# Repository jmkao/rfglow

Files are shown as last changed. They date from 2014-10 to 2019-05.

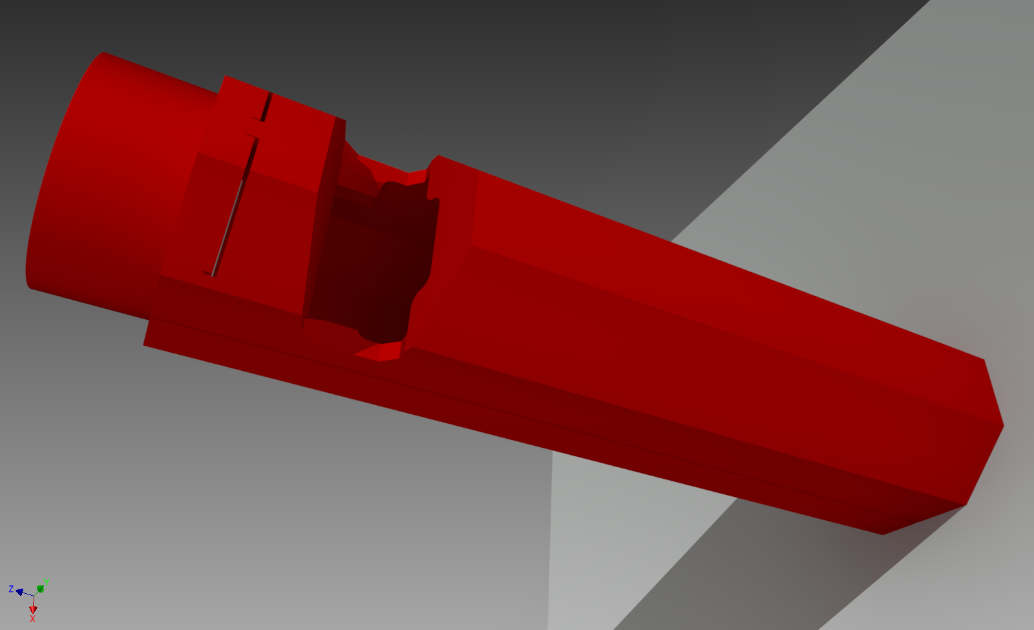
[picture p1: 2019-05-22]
inventor/KBHandle/KBHandle-Assembly.png

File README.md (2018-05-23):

rfglow
======

All the parts for an RF controlled RGB glow stick, in the style of a Ruifan KING BLADE (キングブレード http://ruifan.co.jp/pro_kb_x.html). In fact, making this work requires a diffuser from a KB since the diffuser itself cannot be 3D printed.

There are 3 basic component areas:
 * Electronics (Eagle files and BOM)
 * Microcontroller code (Arduino code)
 * Plastic handle (Inventor IPT files and STL files for 3D printing)

## Project Chat



## Status
This project is fairly usable, although could use some additional polish. All of the areas are sufficiently functional to demonstrate a proof of concept, but requires more testing before a device could actually be used in a physically demanding environment.

The primary items that need work are:
 * App for the BLE master
 * Handle design - Refactor to be more compact and with more practical design, especially for the coupler and attachemnt of the two halves
 * RF Master - Integrate a 0.96" color OLED screen, then design a PCB for it
 * RF Slave - Code something for the button to do

Then there are other interesting things that one could do with a microcontroller:
 * Fade commands
 * Color cycling commands
 * Slaves also act as command repeaters

Contributions welcome in all areas.

# Electronics
The PCB design is in the eagle folder and contains the schematic, PCB layout, and a set of gerber files (zipped together) for sending to a PCB fabrication service like Osh Park or Seeedstudio. (I had my first set made at Osh Park.)

The PCB is really a kind of motherboard for a variety of sub-assemblies (other boards sold as modules), principally:
 * RFBee from Seeedstudio
  * A Panstamp from panstamp.com can also be used as it has the same hardware (and is more compact, even). However, I don't have  board design to accomodate one (yet!)
 * Pololu S7V8A Adjustable Regulator (http://www.pololu.com/product/2118)
  * The potentiometer on this should be adjusted to output 3.7V before putting in place on the board
 * STP04CM05 LED Driver
  * The one I used for this design is a 14-DIP package not officially mentioned on the datasheet. I got mine from Digi-key (http://www.digikey.com/product-detail/en/STP04CM05B1R/497-6940-5-ND/1852497).
 * Vollong 3W RGB High Power Led and a matching lens
  * I got mine from http://www.superbrightleds.com/moreinfo/component-leds/vollong-3w-rgb-high-power-led/899/2214/
  * You'll need to bridge together the - leads into a common cathode configuration (the STP04CM05 is a sink driver)
 * Grove connectors from Seeedstudio cut up
  * I'm sure there's some spec for these, but I had a bunch of these lying around and used them for this purpose. Since you'll have to order an RFBee from them, you might as well get a bunch of cables from them (male on both sides so each cable can make two connectors) and PCB receptacles.
  * The color convention I'm using is:
    * Cable Red --> LED Red
    * Cable White --> LED Green
    * Cable Yellow --> LED Blue
    * Cable Black --> LED Common Ground
 * Adafruit nRF8001 (https://www.adafruit.com/products/1697)
  * Used for the rfglow_ble code which will relay commands from the nRF8001's BLE interface to the glow sticks.
  * Would allow a mobile app (e.g. iOS, Android) on a BLE capable device to control the glow sticks with a more advanced interface
  * A panstamp must be used as the microcontroller to build this device because the nRF8001 must be wired to the hardware SPI interface, and the RFBee does not expose the pins necessary to do this.

The version of the BLE master in this repository is for an unamplified version that uses a Panstamp. There is also an amplified designed that uses a CC1101+CC1190 evaluation module. The schematics and board layout for that were done in Upverter and are available at https://upverter.com/jkao/e86d81299623de9d/RFGlow-BLE-CC1109-Relay/

# Microcontroller Code

Arudino Code for 1.0.x.

 * rfglow_slave
  * Code for the glow sticks themselves
 * rfglow_master
  * Code for a potential master
  * Currently supported gestures:
   * Color change - short press on left and right
   * LED on/off - long press on the center to toggle
   * Auto color cycling mode - short press on center to toggle
   * Brightness change - long press on left or right
 * rfglow_ble
  * BLE based master that will relay color change commands over BLE to the RF glow sticks
  * Usable today for simple color changes with the iOS nRF UART or LightBlue apps
   * For nRF UART, send ASCII of 3 numbers separated by spaces, like "270 255 32\n". This is an HSV value, with the first digit as hue (0-359), second digit as saturation (0-255), and third digit as brightness (0-255)
   * For LightBlue (and really for any app you design yourself), send 4 bytes to the write characteristic of the service. The first 2 bytes are a 16-bit unsigned int for hue (only valid from 0-355), the 3rd byte is the unsigned 8-bit int for saturation, the 4th byte is the unsigned 8-bit int for brightness.
 * rfglow_serial
  * Code for when the master is connected to a computer, in which case you can enter the hue, saturation, and brightness as tuples over the serial line to send the command.
  * This code hasn't been touched in a while, and needs to have the radio settings from rfglow_master copied into it for it to actually work with the current version of rfglow_slave

The Arduino code depends on the following libraries:
 * ShiftPWM from https://github.com/elcojacobs/ShiftPWM
 * Panstamp for Arudino 1.0.x, currently panstamp_library.zip from http://www.panstamp.com/downloads
  * Uses only the CC1101 libraries and not the SWAP stack
 * ClickButton from https://code.google.com/p/clickbutton/downloads/list
  * Only needed by rfglow_master currently for the button behavior

# Plastic Handle

Autodesk Inventor parts and assembly with the current design, to be FFF 3D printed (e.g. <45 degree overhangs, etc...).

This design is quite messy becuase my CAD skills are weak, and the parameters are difficult to adjust. However, it is functional with the following features:
* Lip-and-groove attachment between top and bottom halves to facilitate alignment
 * There is some clearance, so the groove is deeper than the lip sticks out
* Coupler to screw on a king blade diffuser on one end, then attach to the handle
* Cups for magnets to help hold the top and bottom together (0.25" X 0.125" X 0.0625" rare earth)

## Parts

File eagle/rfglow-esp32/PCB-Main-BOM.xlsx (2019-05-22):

Qty | Designator | MPN | Link
2 | R4, R13 | 301010456
1 | R11 | 301010028
1 | C9 | 302010024
1 | USB1 | 320010003
2 | R5, R12 | 301010047
8 | C1, C4, C5, C6, C7, C8, C10, C11 | 302010053
3 | R3, R8, R9 | 301010043
2 | C2, C3 | 302010040
1 | R2 | 301012017
1 | D1 | 304020032
1 | J2 | 320110026
2 | R6, R7 | 301010010
1 | R1 | 301010069
1 | J1 | 320110032
1 | R10 | RC0402JR-0756RL
1 | IC3 | AP2112K-3.3TRG1
1 | U1 | CH340C | https://lcsc.com/product-detail/USB_CH340C_C84681.html
1 | SW1 | 311030001
1 | SW2 | 311020518
1 | Q2 | 305030075
1 | L1 | 303010527
1 | IC1 | TLC59116IPWR | https://lcsc.com/product-detail/LED-Drivers_TI_TLC59116IPWR_TLC59116IPWR_C131194.html
1 | IC2 | TPS63020DSJR | https://lcsc.com/product-detail/DC-DC-Converters_TI_TPS63020DSJR_TPS63020DSJR_C15483.html
1 | Q1 | UMH3NTN | https://lcsc.com/product-detail/Digital-Transistors_ROHM_UMH3NTN_UMH3NTN_C123008.html

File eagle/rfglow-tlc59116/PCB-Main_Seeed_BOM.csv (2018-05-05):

Designator | Manufacturer Part Number | Quantity
C1 | 302010024 | 1
R5 | 301010047 | 1
R8, R9 | 301010509 | 2
C2, C3 | 302010040 | 2
R1, R2, R3, R4 | 301010138 | 4
R6, R7 | 301010010 | 2
J1 | 320110032 | 1
J2 | 320110026 | 1
X1 | 874380643 | 1
SW2 | 311020045 | 1
SW1 | 311030001 | 1
IC1 | TLC59116IPWR | 1
ANT1 | 320110048 | 1
U1 | 310030099 | 1

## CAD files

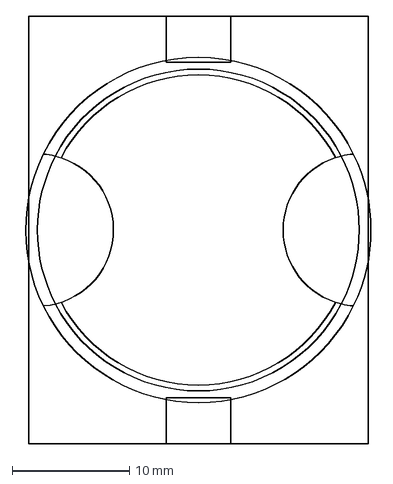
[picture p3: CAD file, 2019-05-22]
inventor/KBHandle/LED Tab Profile.dxf
30.8 x 36.5 mm

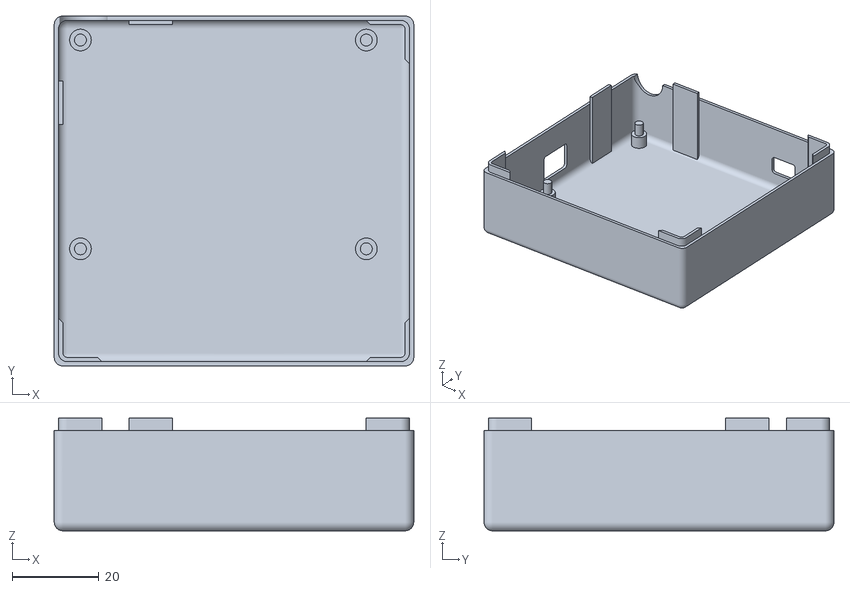
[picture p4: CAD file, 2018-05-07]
models/Box - Part 1.stl
83.0 x 80.8 x 26.0

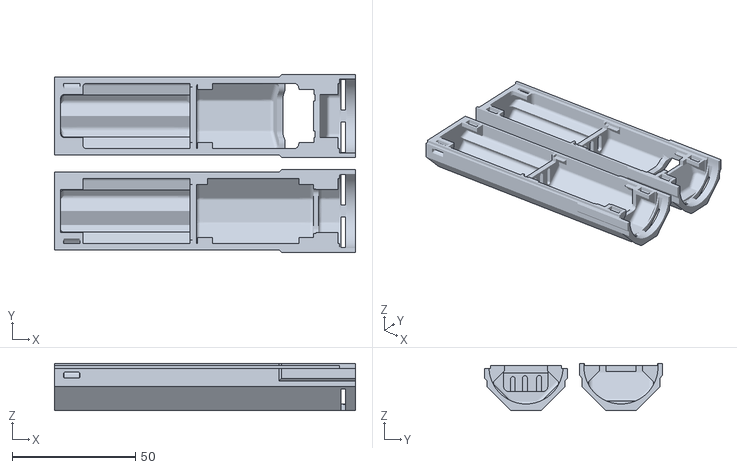
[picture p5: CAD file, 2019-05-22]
inventor/KBHandle/Handle-Set.stl
122.0 x 72.0 x 19.2

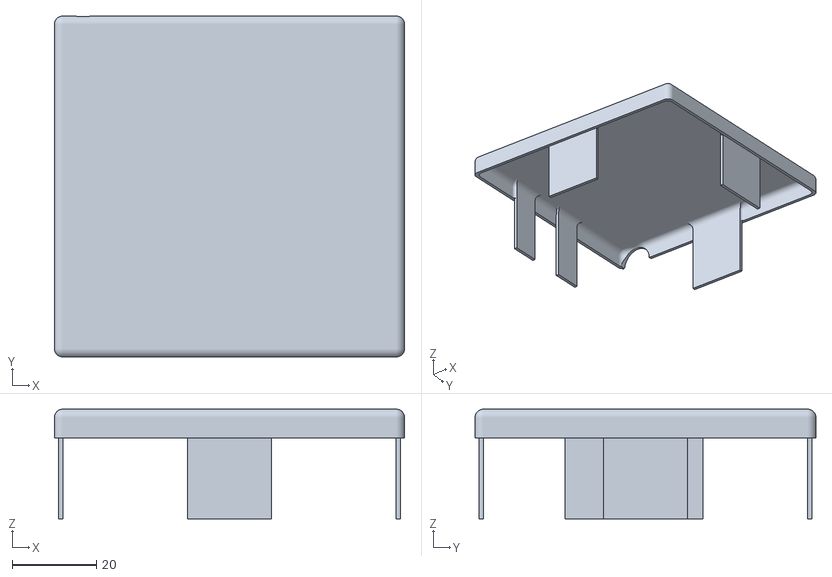
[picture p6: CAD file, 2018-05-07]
models/Box - Part 2.stl
83.0 x 80.8 x 26.0

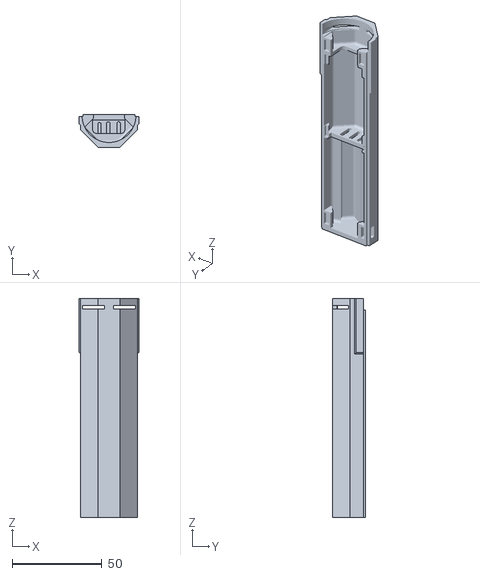
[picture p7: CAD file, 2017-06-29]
inventor/KBHandle/Handle-Bottom.stl
33.5 x 18.2 x 122.0

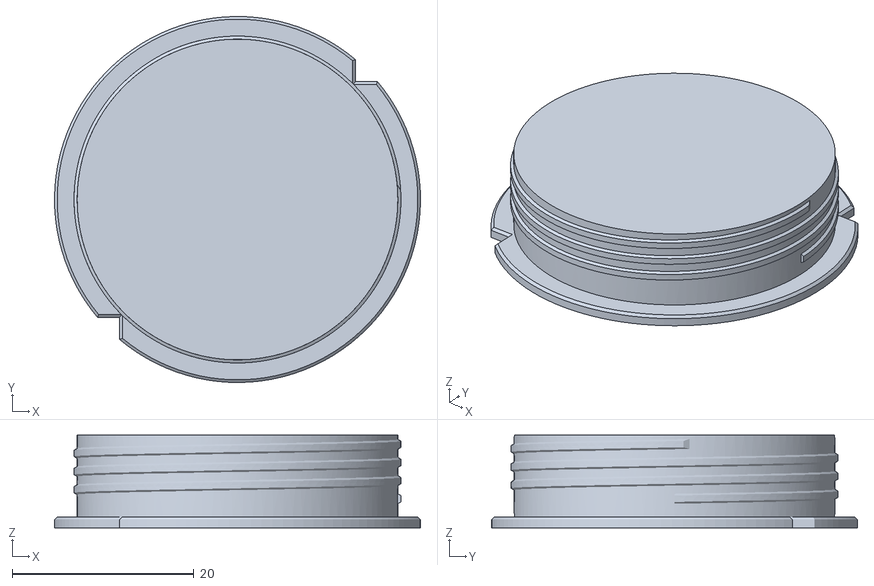
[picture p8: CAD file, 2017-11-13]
models/Cap-Solid.stl
40.3 x 40.3 x 10.2

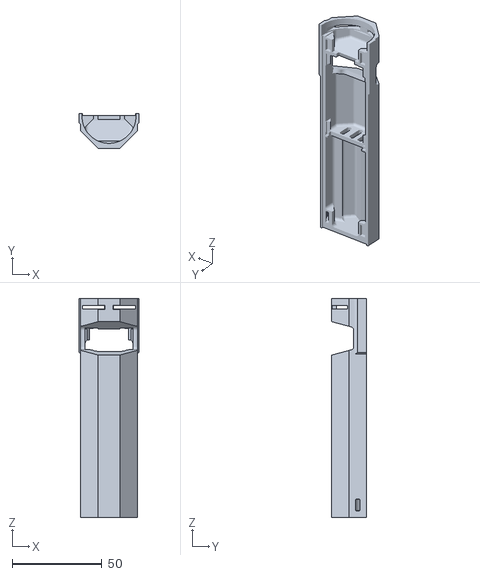
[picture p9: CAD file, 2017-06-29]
inventor/KBHandle/Handle-Top.stl
33.5 x 19.2 x 122.0

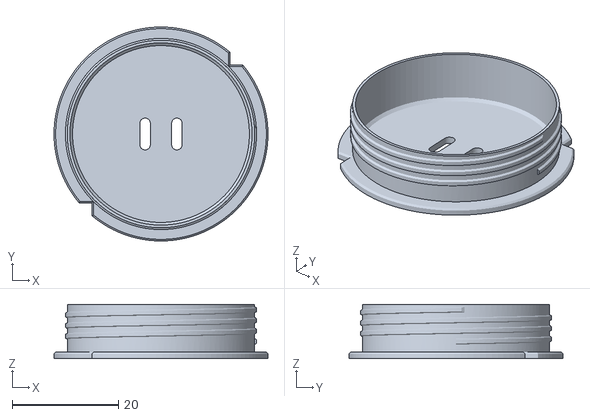
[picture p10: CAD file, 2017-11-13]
models/Cap.stl
40.3 x 40.3 x 10.2

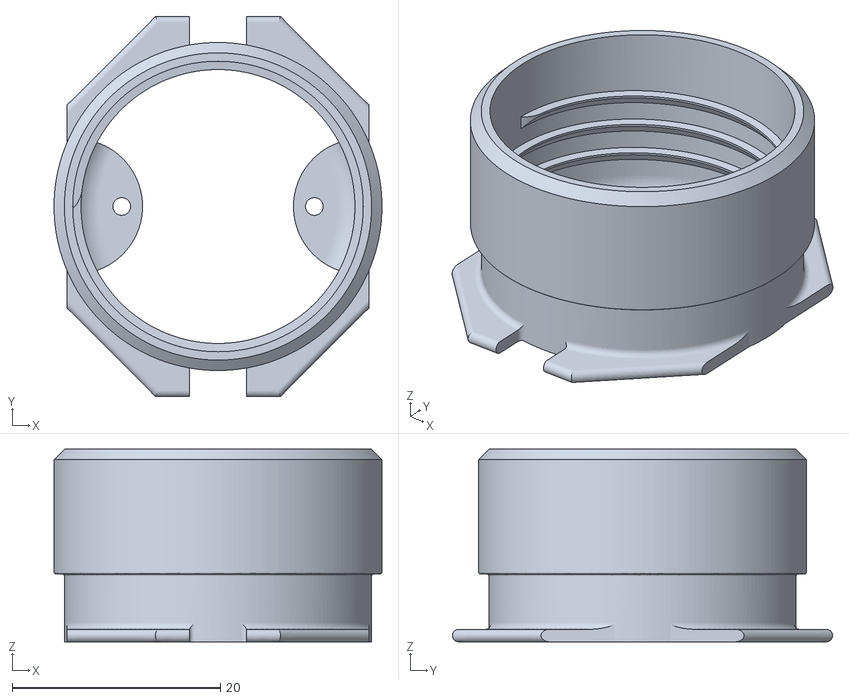
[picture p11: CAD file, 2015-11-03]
inventor/KBHandle/DiffuserCoupler.stl
31.5 x 36.5 x 18.5

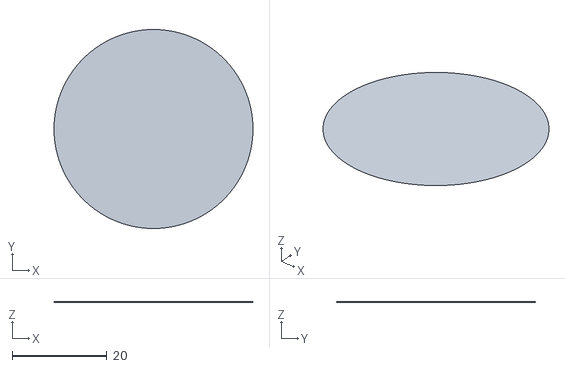
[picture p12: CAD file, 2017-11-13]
models/Cylinder.stl
42.0 x 42.0 x 0.02

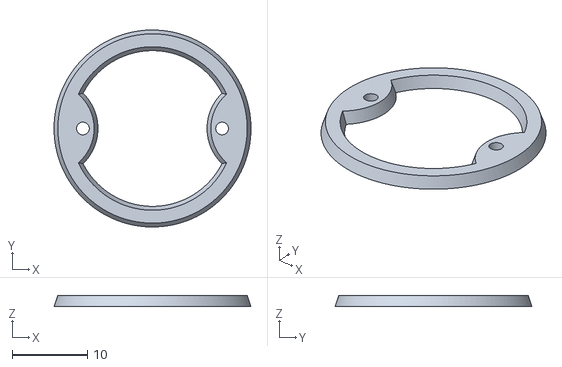
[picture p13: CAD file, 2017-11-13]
models/Coupler.stl
26.2 x 26.2 x 1.50

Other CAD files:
inventor/KBHandle/DiffuserCoupler.ipt
inventor/KBHandle/Handle-Bottom.ipt
inventor/KBHandle/Handle-Top-Battery.ipt
inventor/KBHandle/Handle-Top-Main.ipt
inventor/KBHandle/Handle-Top.ipt
inventor/KBHandle/KBHandle.iam

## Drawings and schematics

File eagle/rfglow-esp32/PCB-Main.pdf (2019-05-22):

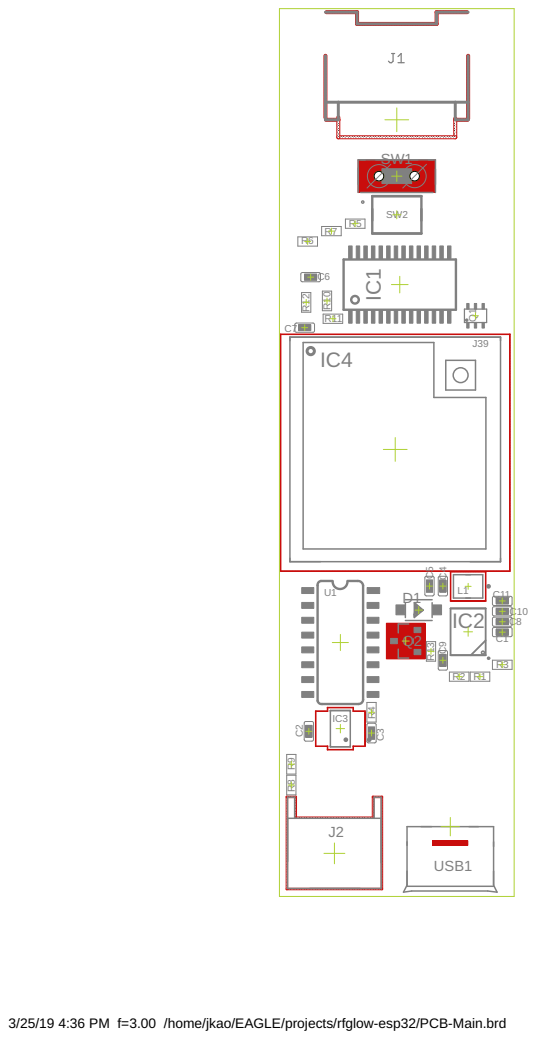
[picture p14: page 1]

R5
R7
R6

3/25/19 4:36 PM f=3.00 /home/jkao/EAGLE/projects/rfglow-esp32/PCB-Main.brd

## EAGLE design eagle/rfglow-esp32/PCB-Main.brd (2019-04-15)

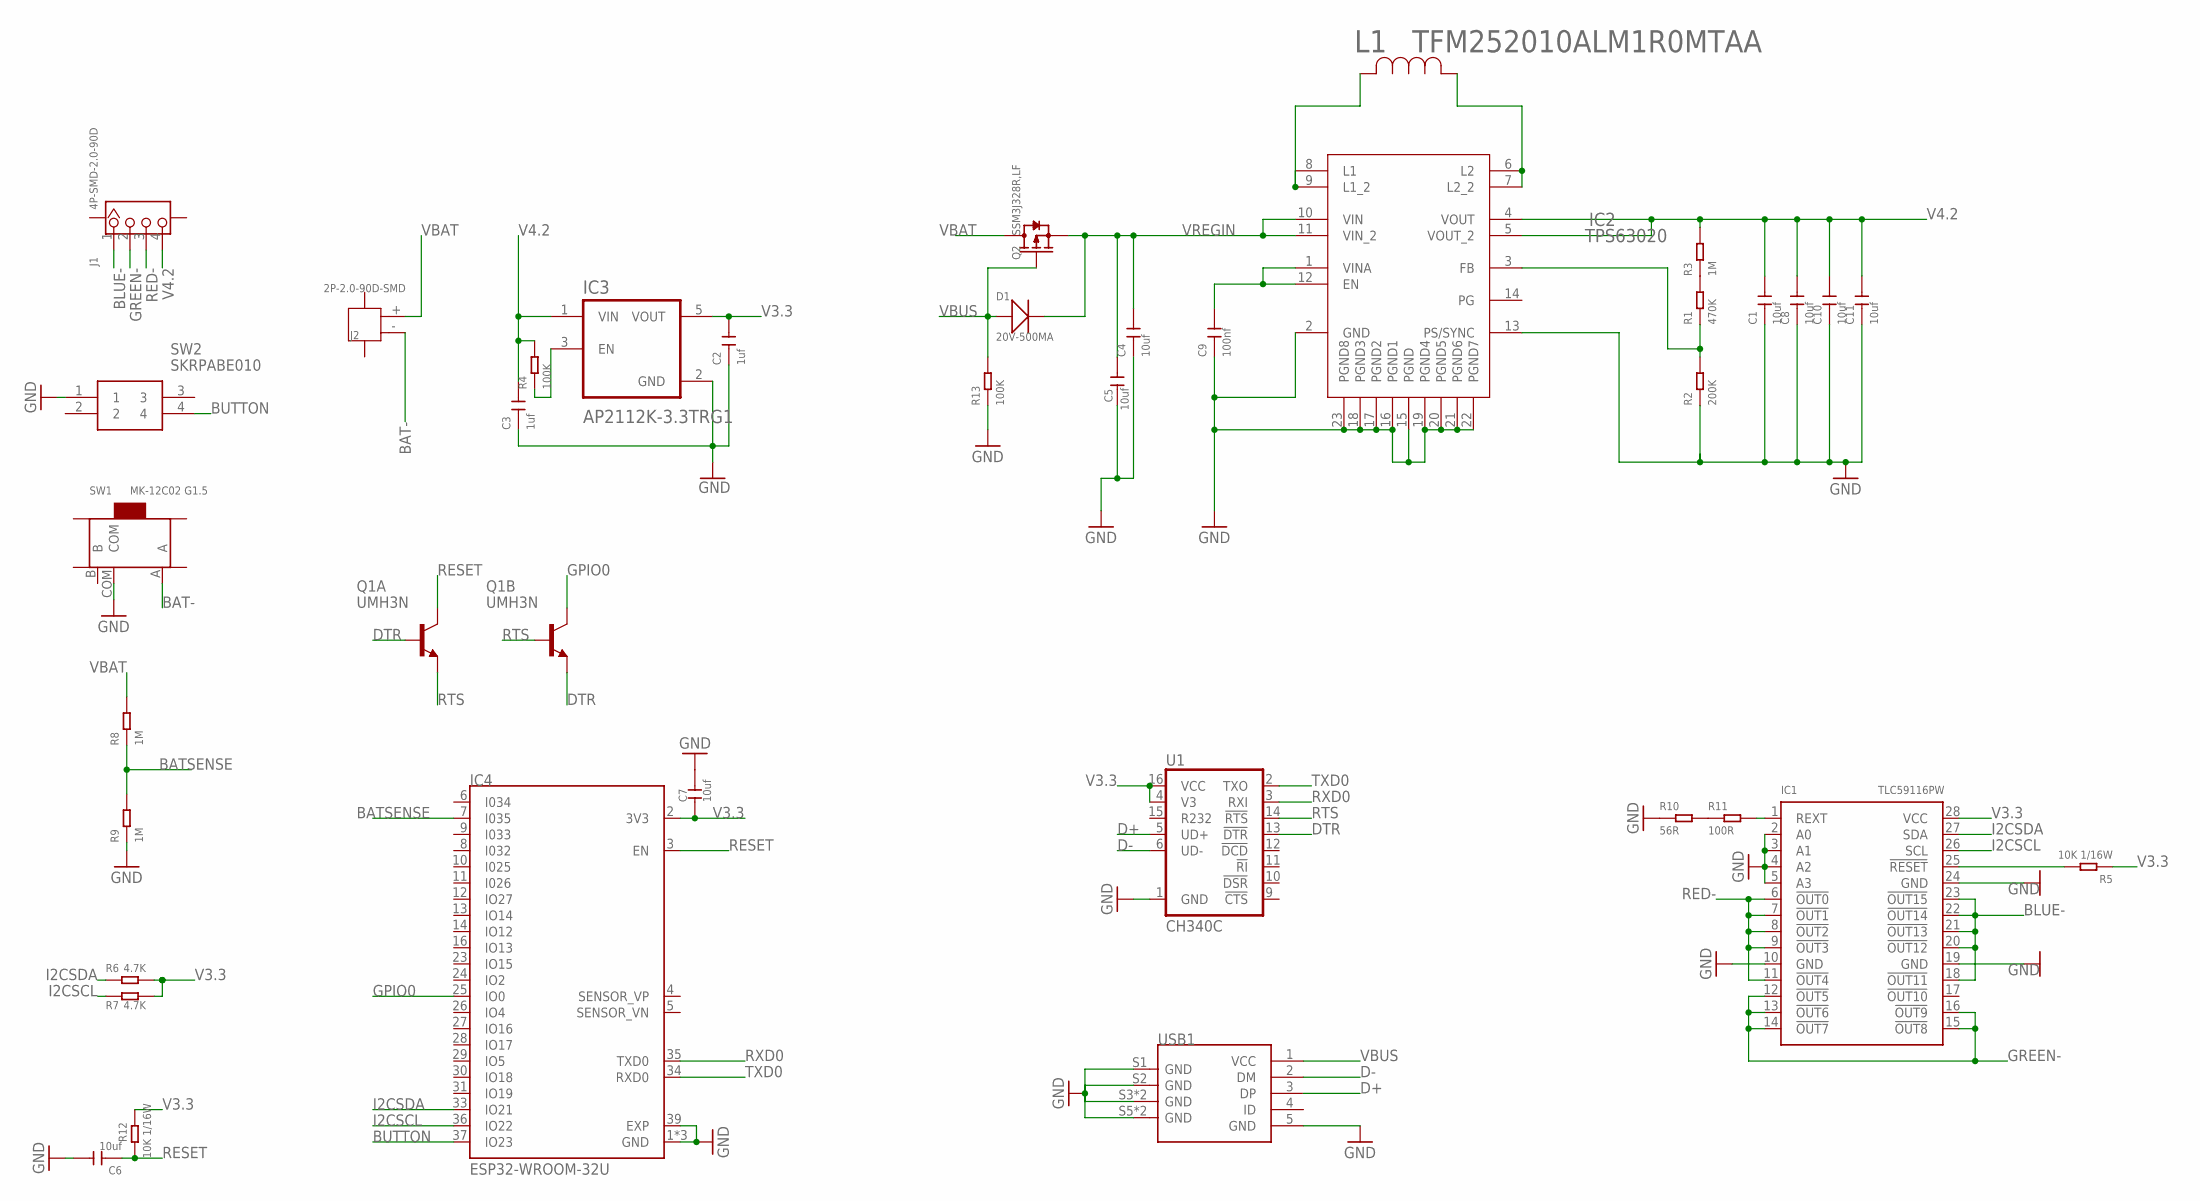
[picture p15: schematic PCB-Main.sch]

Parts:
C1, C4, C5, C6, C7, C8, C10, C11: 10uf; C0402
C2, C3: 1uf; C0402
C9: 100nf; C0402
D1: 20V-500MA; SOD-123
IC1: TLC59116PW; PW_R-PDSO-G28
IC2: TPS63020; QFN14-3X4MM
IC3: AP2112K-3.3TRG1; SOT95P285X140-5N
IC4: ESP32-WROOM-32U; XCVR_ESP32-WROOM-32U
J1: 4P-SMD-2.0-90D; HW4-SMD-2.0-90D
J2: 2P-2.0-90D-SMD; HW2-SMD-2.0-90D
L1: TFM252010ALM1R0MTAA; IND_1008
Q1: UMH3N; UMT6
Q2: SSM3J328R,LF; SOT-23
R1: 470K; R0402
R2: 200K; R0402
R3, R8, R9: 1M; R0402
R4, R13: 100K; R0402
R5, R12: 10K 1/16W; R0402
R6, R7: 4.7K; R0402
R10: 56R; R0402
R11: 100R; R0402
SW1: MK-12C02 G1.5; SW7-SMD-L6.7X2.7X3.2MM
SW2: SKRPABE010; SMT(4.2X3.2)
U1: CH340C; SO016
USB1: 10118193-0001LF; MICRO-USB5+6P-SMD-0.65-B

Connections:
BAT-: J2.- (2), SW1.A
BATSENSE: IC4.7 (I035), R8.1, R9.2
BLUE-: IC1.18 (!OUT11), IC1.20 (!OUT12), IC1.21 (!OUT13), IC1.22 (!OUT14), IC1.23 (!OUT15), J1.1
BUTTON: IC4.37 (IO23), SW2.4
D+: U1.5 (UD+), USB1.3 (DP)
D-: U1.6 (UD-), USB1.2 (DM)
DTR: Q1.2 (B), Q1.4 (E), U1.13 (!DTR)
GND: C1.1, C2.1, C3.1, C4.1, C5.1, C6.2, C7.2, C8.1, C9.1, C10.1, C11.1, IC1.2 (A0), IC1.3 (A1), IC1.4 (A2), IC1.5 (A3), IC1.10 (GND), IC1.19 (GND), IC1.24 (GND), IC2.2 (GND), IC2.13 (PS/SYNC), IC2.15 (PGND), IC2.16 (PGND1), IC2.17 (PGND2), IC2.18 (PGND3), IC2.19 (PGND4), IC2.20 (PGND5), IC2.21 (PGND6), IC2.22 (PGND7), IC2.23 (PGND8), IC3.2 (GND), IC4.1 (GND), IC4.15 (GND), IC4.38 (GND), IC4.39 (EXP), R2.1, R9.1, R10.1, R13.1, SW1.COM, SW2.1, U1.1 (GND), USB1.5 (GND), USB1.S1 (GND), USB1.S2 (GND), USB1.S3 (GND), USB1.S4 (GND), USB1.S5 (GND), USB1.S6 (GND)
GPIO0: IC4.25 (IO0), Q1.3 (C)
GREEN-: IC1.12 (!OUT5), IC1.13 (!OUT6), IC1.14 (!OUT7), IC1.15 (!OUT8), IC1.16 (!OUT9), J1.2
I2CSCL: IC1.26 (SCL), IC4.36 (IO22), R7.1
I2CSDA: IC1.27 (SDA), IC4.33 (IO21), R6.1
unnamed: C9.2, IC2.1 (VINA), IC2.12 (EN)
unnamed: IC1.1 (REXT), R11.2
unnamed: R1.2, R3.1
unnamed: IC3.3 (EN), R4.1
unnamed: R10.2, R11.1
unnamed: IC2.8 (L1), IC2.9 (L1_2), L1.2
unnamed: IC1.25 (!RESET), R5.2
unnamed: IC2.6 (L2), IC2.7 (L2_2), L1.1
unnamed: IC2.3 (FB), R1.1, R2.2
RED-: IC1.6 (!OUT0), IC1.7 (!OUT1), IC1.8 (!OUT2), IC1.9 (!OUT3), IC1.11 (!OUT4), J1.3
RESET: C6.1, IC4.3 (EN), Q1.6 (C), R12.1
RTS: Q1.1 (E), Q1.5 (B), U1.14 (!RTS)
RXD0: IC4.35 (TXD0), U1.3 (RXI)
TXD0: IC4.34 (RXD0), U1.2 (TXO)
V3.3: C2.2, C7.1, IC1.28 (VCC), IC3.5 (VOUT), IC4.2 (3V3), R5.1, R6.2, R7.2, R12.2, U1.4 (V3), U1.16 (VCC)
V4.2: C1.2, C3.2, C8.2, C10.2, C11.2, IC2.4 (VOUT), IC2.5 (VOUT_2), IC3.1 (VIN), J1.4, R3.2, R4.2
VBAT: J2.+ (1), Q2.3 (D), R8.2
VBUS: D1.+, Q2.1 (G), R13.2, USB1.1 (VCC)
VREGIN: C4.2, C5.2, D1.-, IC2.10 (VIN), IC2.11 (VIN_2), Q2.2 (S)

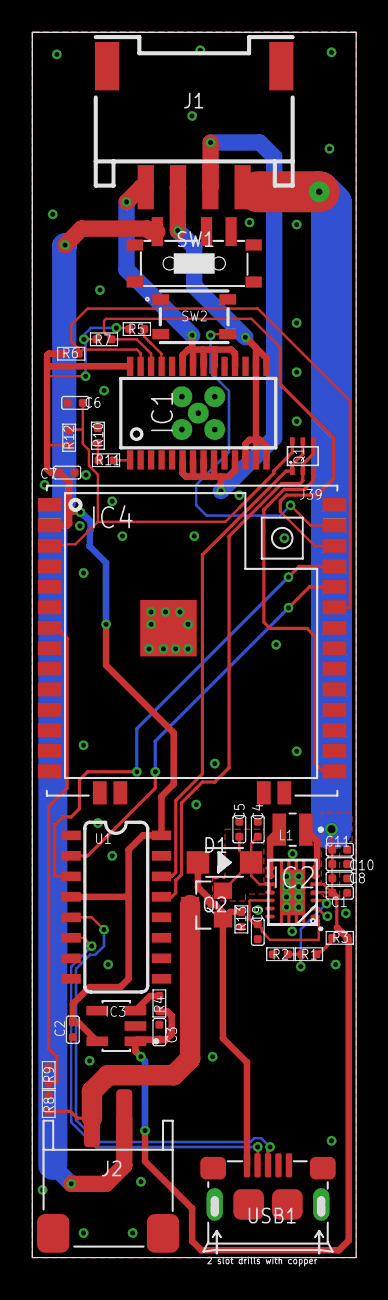
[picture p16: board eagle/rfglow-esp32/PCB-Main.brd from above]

Board: 2 copper layers, 20.1 x 75.9 mm, 38 parts (0 on the bottom side), 31 nets.

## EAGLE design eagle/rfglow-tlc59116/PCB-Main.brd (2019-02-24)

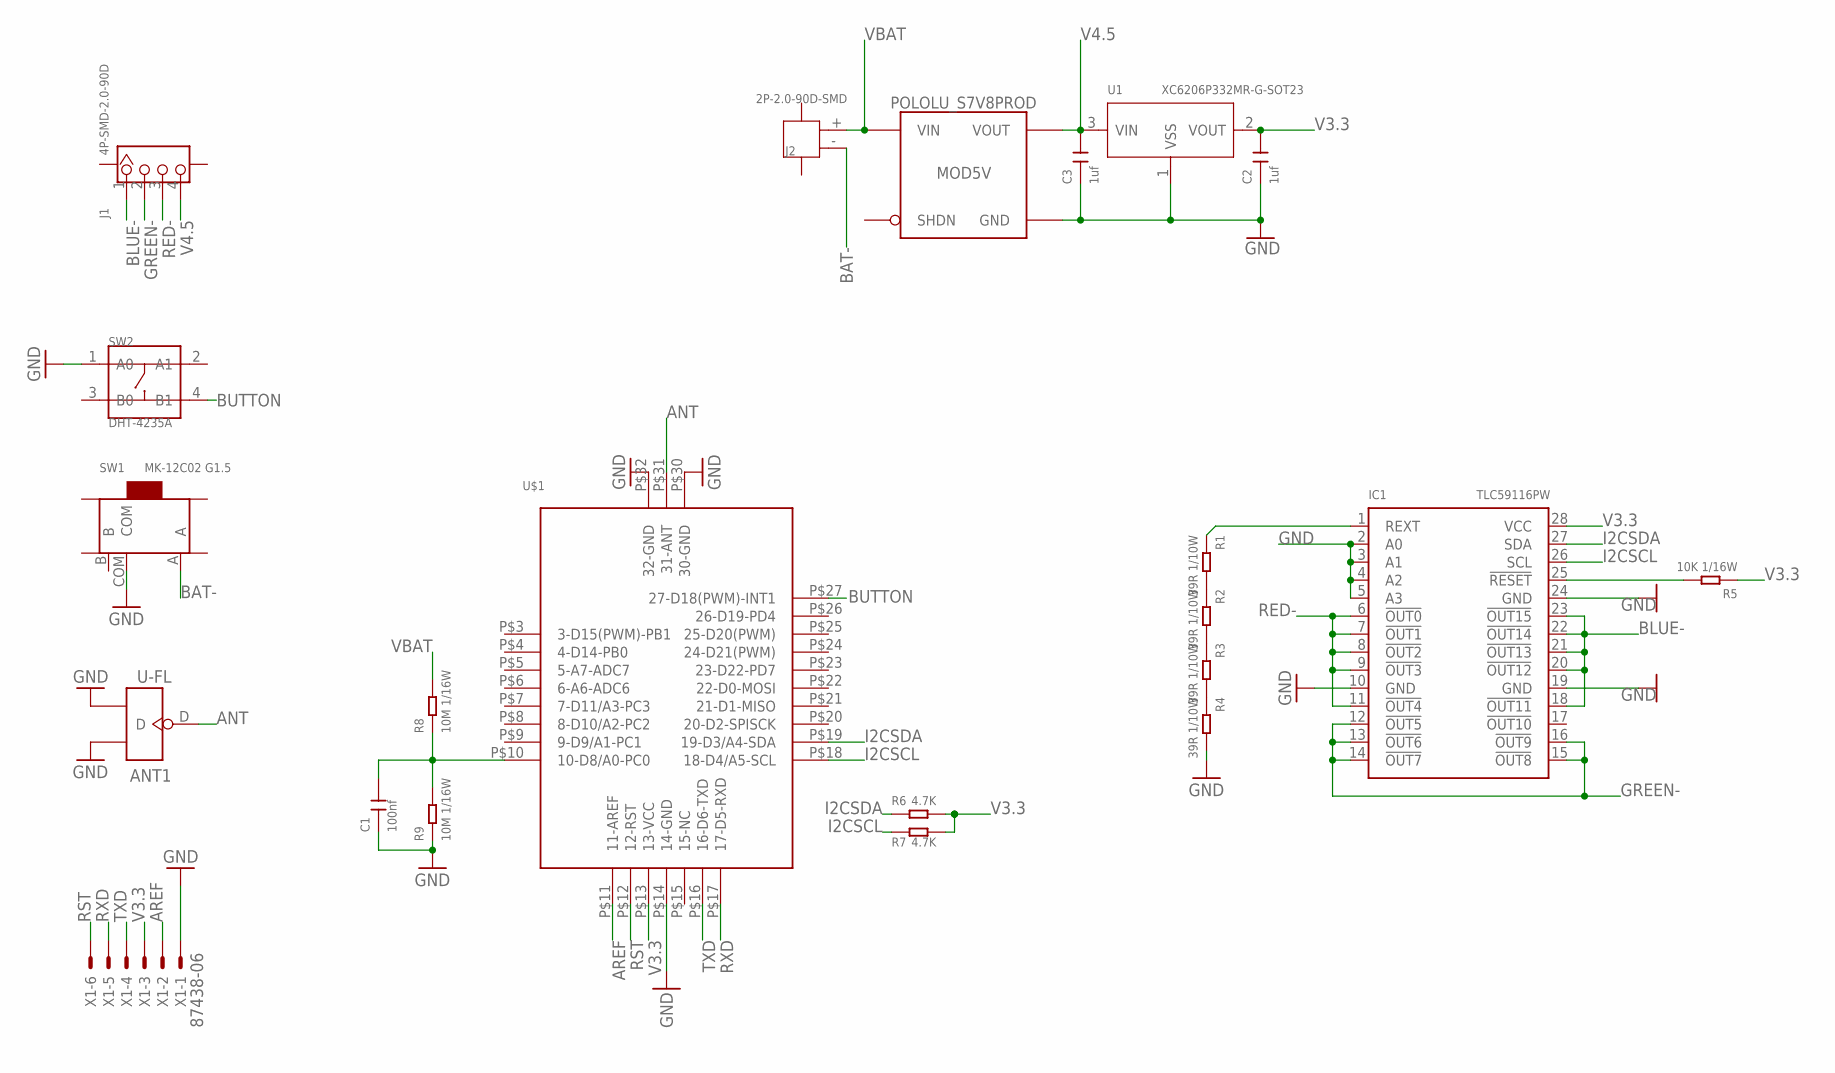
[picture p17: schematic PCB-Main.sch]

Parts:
ANT1: U-FL; U-FL3P-SMD-2.6X2.6X1.0MM
C1: 100nf; C0402
C2, C3: 1uf; C0402
IC1: TLC59116PW; PW_R-PDSO-G28
J1: 4P-SMD-2.0-90D; HW4-SMD-2.0-90D
J2: 2P-2.0-90D-SMD; HW2-SMD-2.0-90D
MOD5V: POLOLU_S7V8PROD; POLOLU_4P_SIGO
R1, R2, R3, R4: 39R 1/10W; R0603
R5: 10K 1/16W; R0402
R6, R7: 4.7K; R0402
R8, R9: 10M 1/16W; R0402
SW1: MK-12C02 G1.5; SW7-SMD-L6.7X2.7X3.2MM
SW2: DHT-4235A; SW4-SMD-4.2X3.2X2.5MM
U1: XC6206P332MR-G-SOT23; SOT-23
U$1: PANSTAMP-AVR-2; SMD-PAD-34
X1: 87438-06

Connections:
ANT: ANT1.D, U$1.P$31 (31-ANT)
AREF: U$1.P$11 (11-AREF), X1.2
BAT-: J2.- (2), SW1.A
BLUE-: IC1.18 (!OUT11), IC1.20 (!OUT12), IC1.21 (!OUT13), IC1.22 (!OUT14), IC1.23 (!OUT15), J1.1
BUTTON: SW2.4 (B1), U$1.P$27 (27-D18(PWM)-INT1)
GND: ANT1.GND1, ANT1.GND2, C1.1, C2.1, C3.1, IC1.2 (A0), IC1.3 (A1), IC1.4 (A2), IC1.5 (A3), IC1.10 (GND), IC1.19 (GND), IC1.24 (GND), MOD5V.G (GND), R4.2, R9.1, SW1.COM, SW2.1 (A0), U1.1 (VSS), U$1.P$14 (14-GND), U$1.P$30 (30-GND), U$1.P$32 (32-GND), X1.1
GREEN-: IC1.12 (!OUT5), IC1.13 (!OUT6), IC1.14 (!OUT7), IC1.15 (!OUT8), IC1.16 (!OUT9), J1.2
I2CSCL: IC1.26 (SCL), R7.1, U$1.P$18 (18-D4/A5-SCL)
I2CSDA: IC1.27 (SDA), R6.1, U$1.P$19 (19-D3/A4-SDA)
unnamed: R1.2, R2.1
unnamed: R2.2, R3.1
unnamed: R3.2, R4.1
unnamed: IC1.25 (!RESET), R5.2
unnamed: IC1.1 (REXT), R1.1
unnamed: C1.2, R8.1, R9.2, U$1.P$10 (10-D8/A0-PC0)
RED-: IC1.6 (!OUT0), IC1.7 (!OUT1), IC1.8 (!OUT2), IC1.9 (!OUT3), IC1.11 (!OUT4), J1.3
RST: U$1.P$12 (12-RST), X1.6
RXD: U$1.P$17 (17-D5-RXD), X1.5
TXD: U$1.P$16 (16-D6-TXD), X1.4
V3.3: C2.2, IC1.28 (VCC), R5.1, R6.2, R7.2, U1.2 (VOUT), U$1.P$13 (13-VCC), X1.3
V4.5: C3.2, J1.4, MOD5V.O (VOUT), U1.3 (VIN)
VBAT: J2.+ (1), MOD5V.I (VIN), R8.2

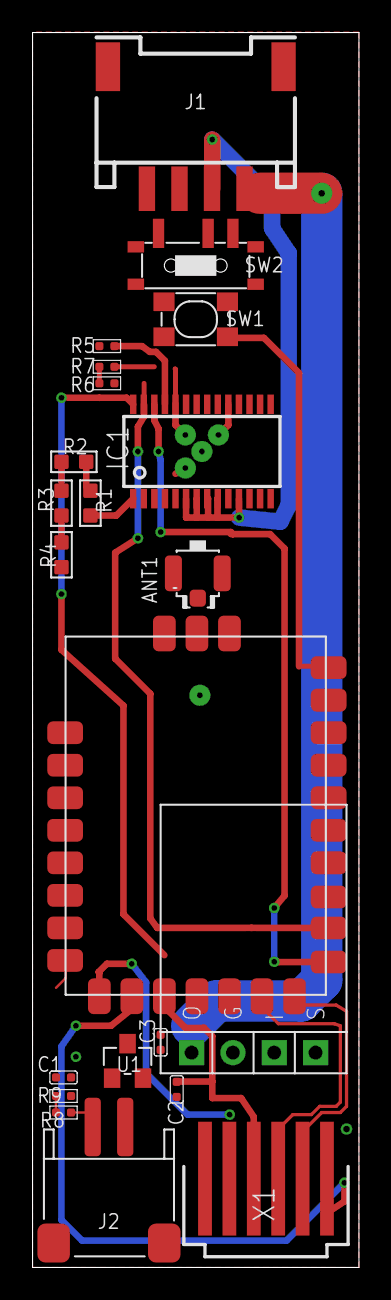
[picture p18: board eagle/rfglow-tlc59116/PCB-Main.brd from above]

Board: 2 copper layers, 20.1 x 75.9 mm, 22 parts (0 on the bottom side), 22 nets.

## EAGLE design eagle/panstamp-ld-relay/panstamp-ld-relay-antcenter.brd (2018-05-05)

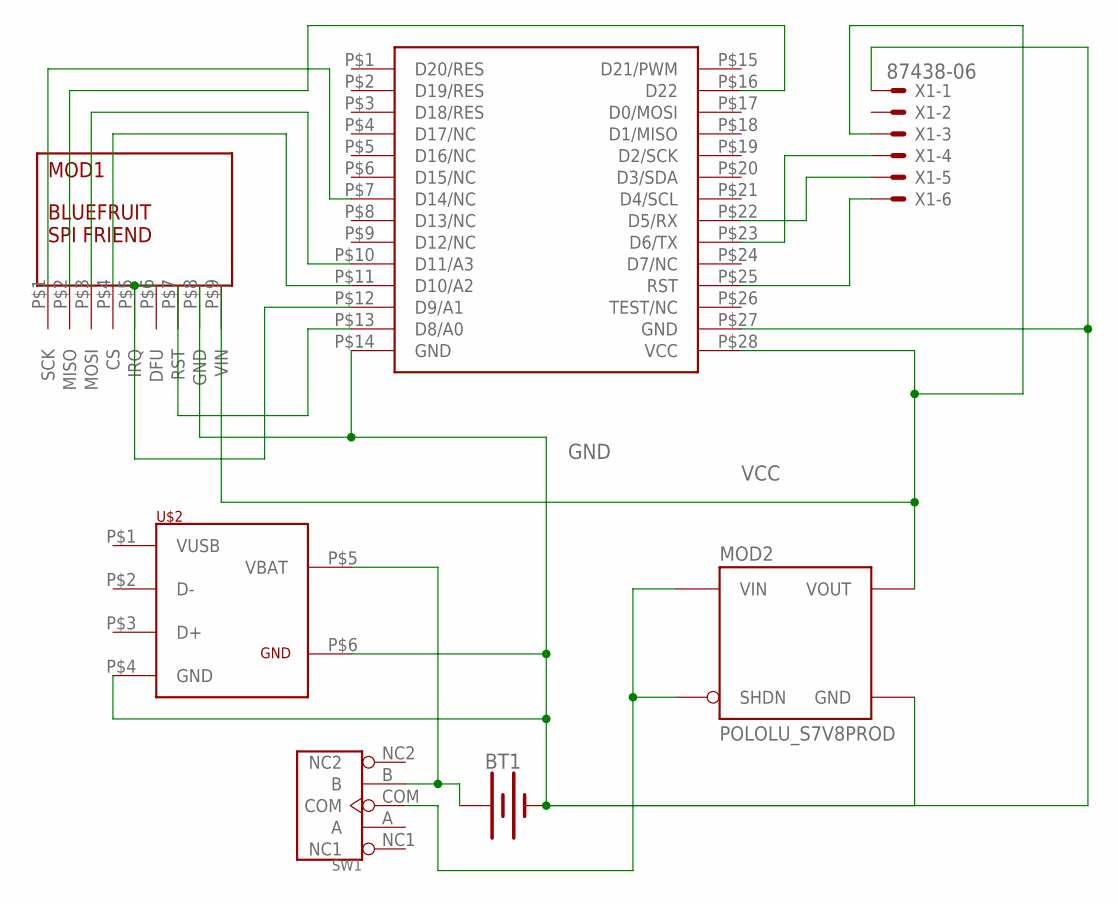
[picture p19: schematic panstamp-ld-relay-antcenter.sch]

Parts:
BT1: BATTERY-18650; BATTERY_18650-HOLDER
MOD1: BLUEFRUIT-SPI
MOD2: POLOLU_S7V8PROD; POLOLU_4P_SIGO
SW1: DIP-TOGGLE-SWITCH-ON-ON(3+2P-8.8X4.6MM)-90D; SW5-2.0-8.8X4.4X4.7MM-90D
U$1: PANSTAMP-LD
U$2: JS-1965
X1: 87438-06

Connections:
GND: BT1.GND@1 (-), MOD1.P$8 (GND), MOD2.G (GND), U$1.P$14 (GND), U$1.P$27 (GND), U$2.P$4 (GND), U$2.P$6 (GND), X1.1
unnamed: U$1.P$23 (D6/TX), X1.4
unnamed: MOD1.P$2 (MISO), U$1.P$16 (D22)
unnamed: MOD1.P$4 (CS), U$1.P$11 (D10/A2)
unnamed: MOD1.P$3 (MOSI), U$1.P$10 (D11/A3)
unnamed: MOD1.P$7 (RST), U$1.P$13 (D8/A0)
unnamed: MOD1.P$1 (SCK), U$1.P$7 (D14/NC)
unnamed: MOD2.I (VIN), MOD2.S (SHDN), SW1.COM
unnamed: MOD1.P$5 (IRQ), U$1.P$12 (D9/A1)
unnamed: U$1.P$22 (D5/RX), X1.5
unnamed: U$1.P$25 (RST), X1.6
VBAT: BT1.PWR@1 (+), SW1.B, U$2.P$5 (VBAT)
VCC: MOD1.P$9 (VIN), MOD2.O (VOUT), U$1.P$28 (VCC), X1.3

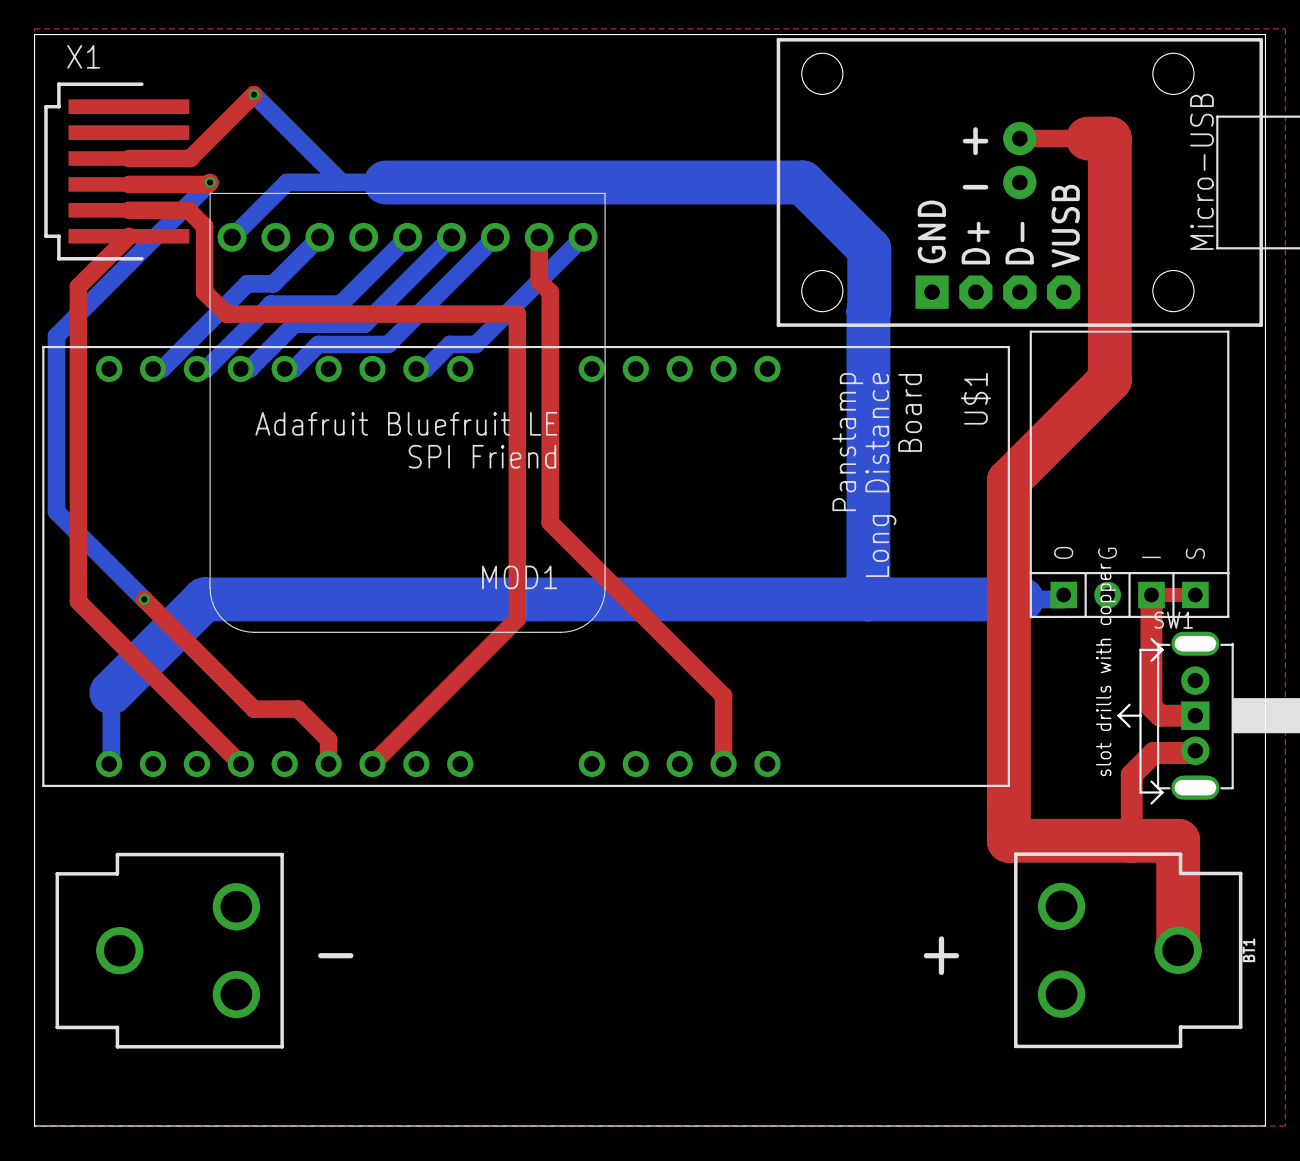
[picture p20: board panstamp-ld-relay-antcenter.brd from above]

Board: 2 copper layers, 71.2 x 63.2 mm, 7 parts (0 on the bottom side), 13 nets.

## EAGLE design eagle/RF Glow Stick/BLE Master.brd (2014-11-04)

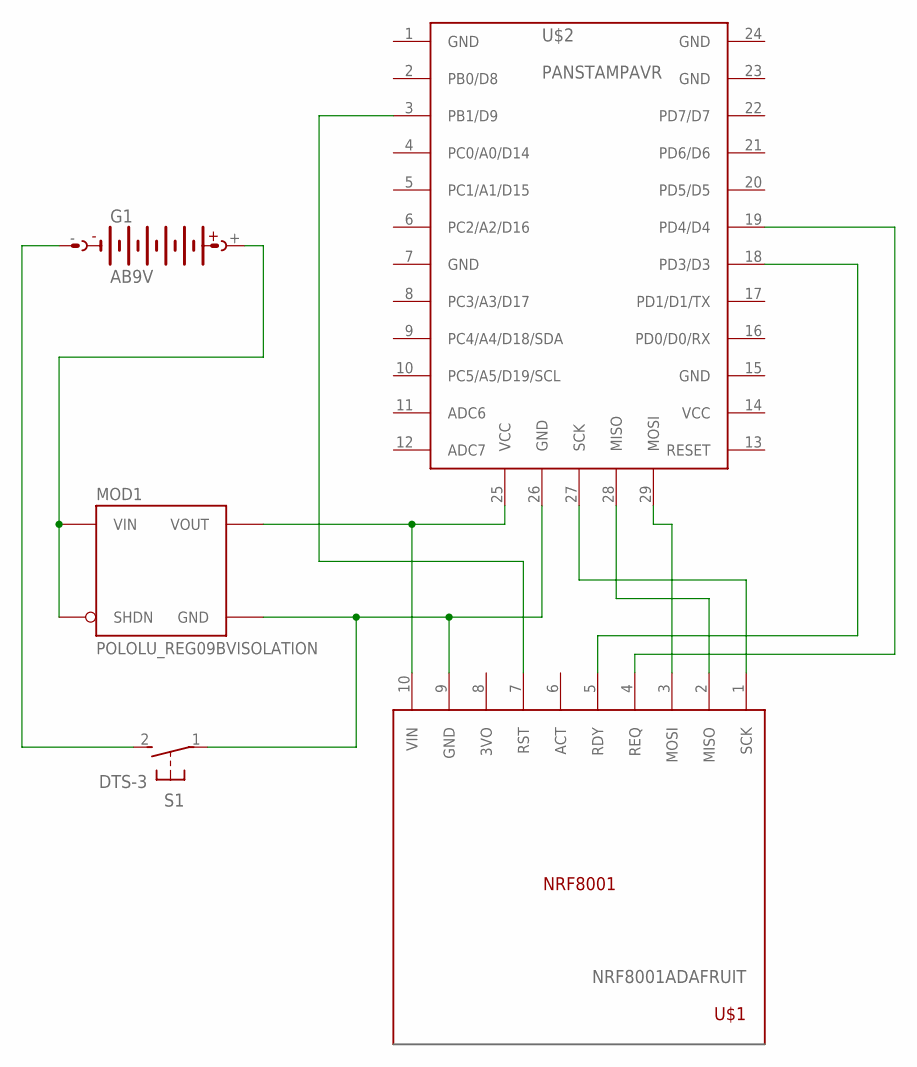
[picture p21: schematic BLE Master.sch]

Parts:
G1: AB9V
MOD1: POLOLU_REG09BVISOLATION; POLOLU_REG09B_ISO
S1: DTS-3
U$1: NRF8001ADAFRUIT; NRF8001_ADAFRUIT
U$2: PANSTAMPAVR; PANSTAMP

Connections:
unnamed: G1.+, MOD1.I (VIN), MOD1.S (SHDN)
unnamed: G1.-, S1.2
unnamed: MOD1.G (GND), S1.1, U$1.9 (GND), U$2.26 (GND)
unnamed: U$1.1 (SCK), U$2.27 (SCK)
unnamed: U$1.2 (MISO), U$2.28 (MISO)
unnamed: U$1.3 (MOSI), U$2.29 (MOSI)
unnamed: U$1.4 (REQ), U$2.19 (PD4/D4)
unnamed: U$1.5 (RDY), U$2.18 (PD3/D3)
unnamed: U$1.7 (RST), U$2.3 (PB1/D9)
unnamed: MOD1.O (VOUT), U$1.10 (VIN), U$2.25 (VCC)

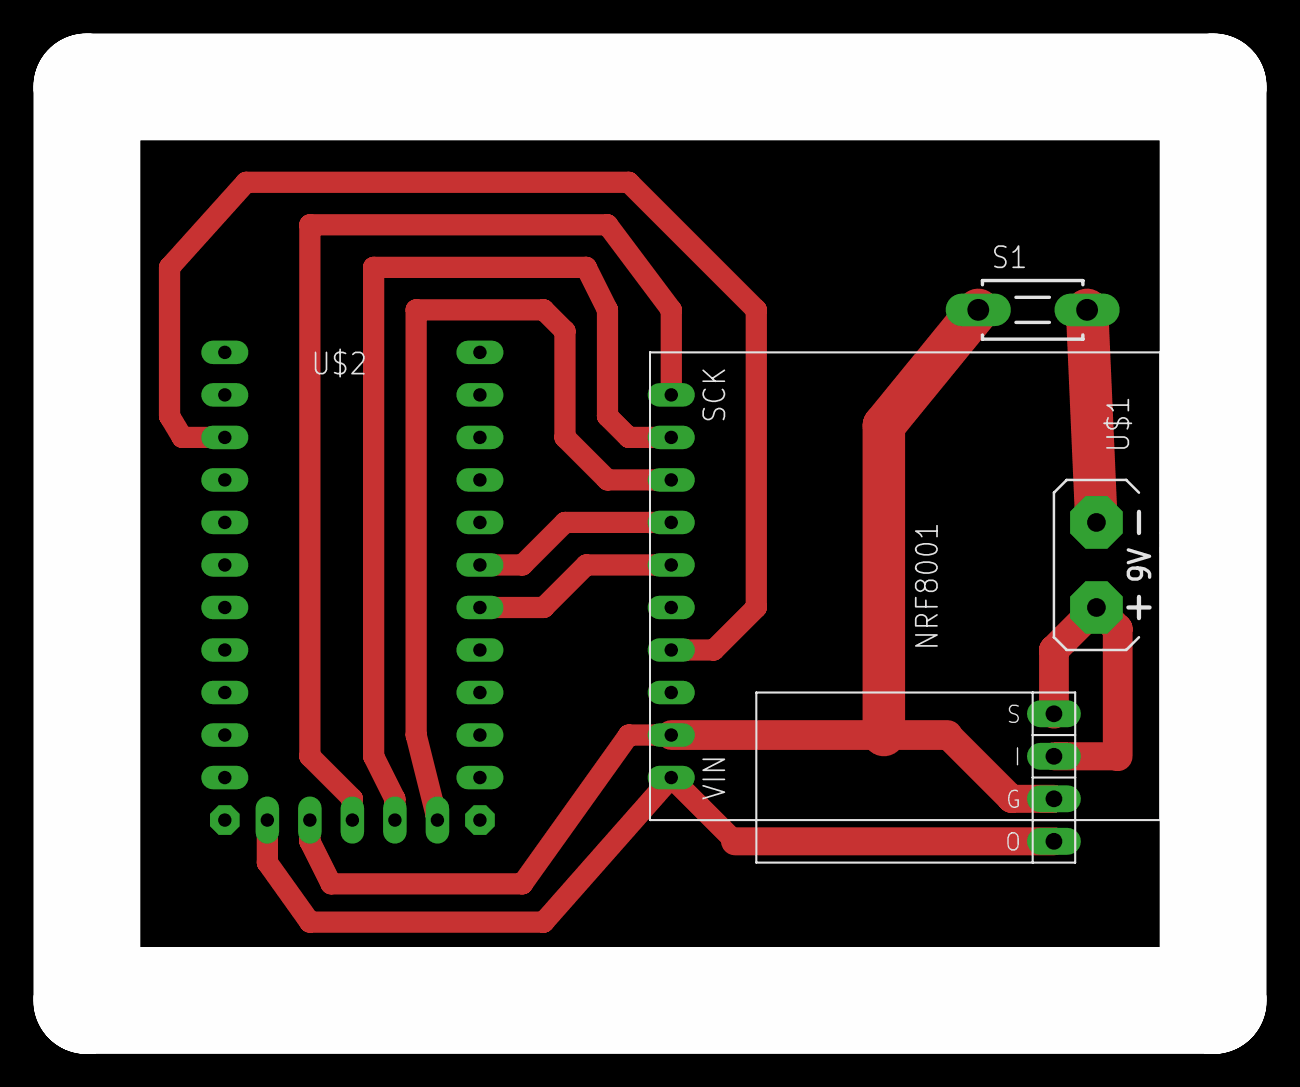
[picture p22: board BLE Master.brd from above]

Board: 2 copper layers, 67.3 x 54.6 mm, 5 parts (0 on the bottom side), 10 nets.

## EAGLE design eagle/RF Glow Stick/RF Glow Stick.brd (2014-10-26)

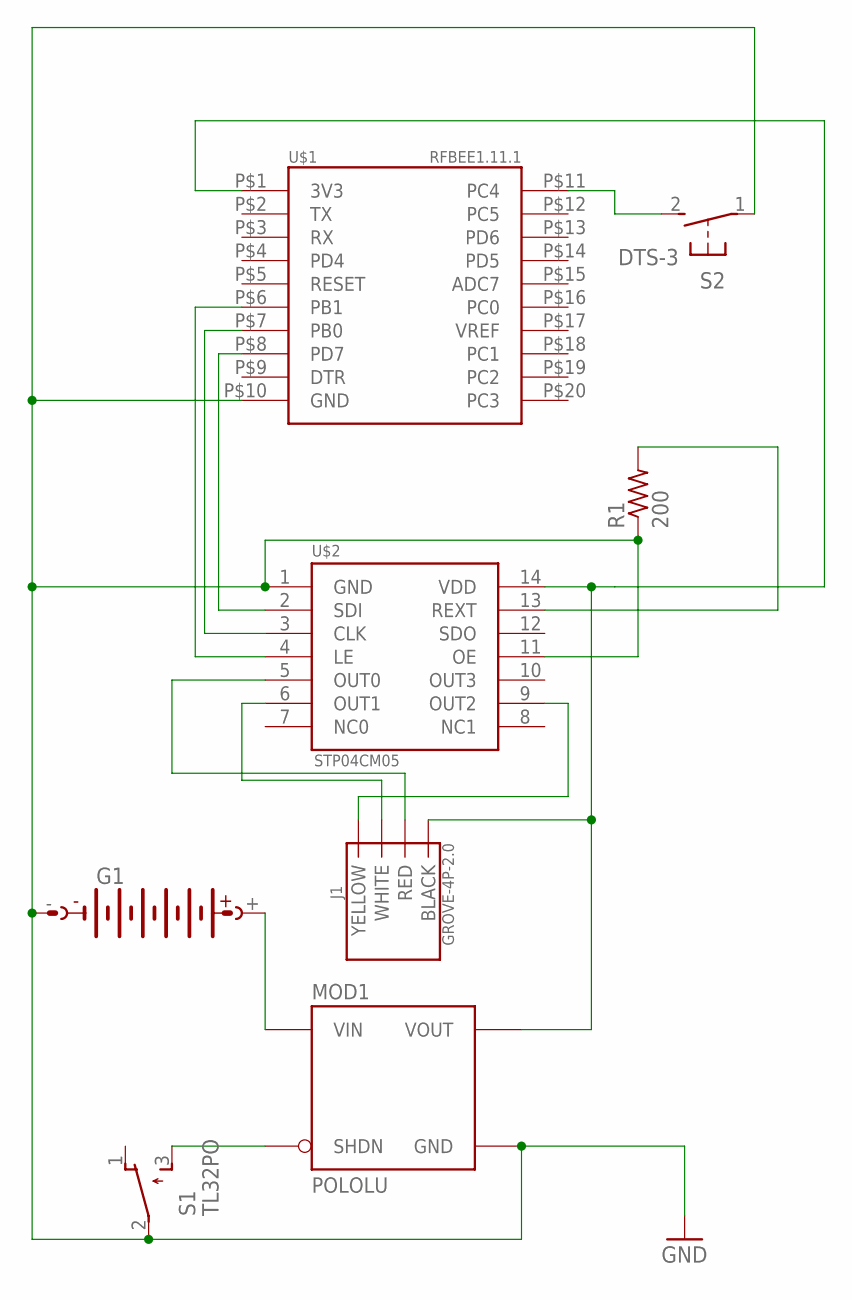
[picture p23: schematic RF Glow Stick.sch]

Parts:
G1: AB9V
J1: GROVE-4P-2.0; 4P-2.0-90D
MOD1: POLOLU; POLOLU_REG09B
R1: 200; 0309/12
S1: TL32PO; TL3XPO
S2: DTS-3
U$1: RFBEE1.11.1; RFBEE
U$2: STP04CM05; DIL14

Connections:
BATT: G1.+, MOD1.I (VIN)
GND: G1.-, MOD1.G (GND), R1.1, S1.2, S2.1, U$1.P$10 (GND), U$2.1 (GND), U$2.11 (OE)
unnamed: J1.RED, U$2.5 (OUT0)
unnamed: MOD1.S (SHDN), S1.3 (S)
unnamed: S2.2, U$1.P$11 (PC4)
unnamed: U$1.P$6 (PB1), U$2.4 (LE)
unnamed: U$1.P$7 (PB0), U$2.3 (CLK)
unnamed: U$1.P$8 (PD7), U$2.2 (SDI)
unnamed: J1.WHITE, U$2.6 (OUT1)
unnamed: J1.YELLOW, U$2.9 (OUT2)
unnamed: R1.2, U$2.13 (REXT)
VOUT: J1.BLACK, MOD1.O (VOUT), U$1.P$1 (3V3), U$2.14 (VDD)

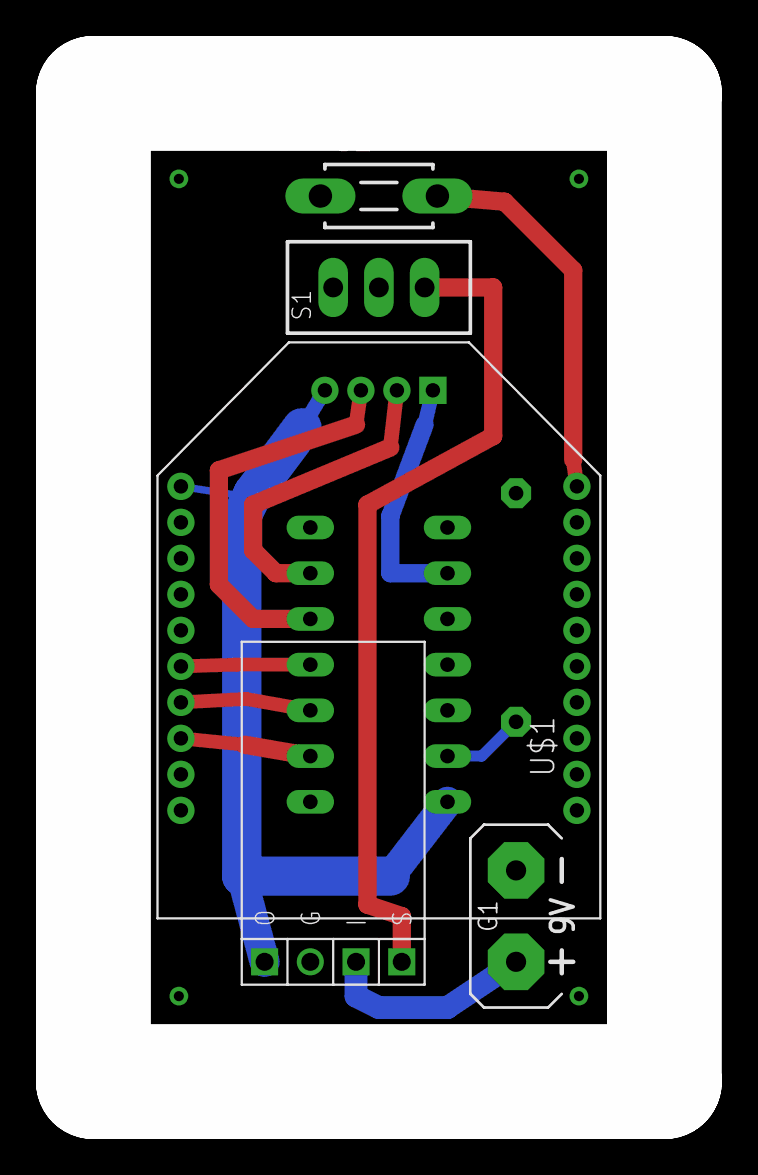
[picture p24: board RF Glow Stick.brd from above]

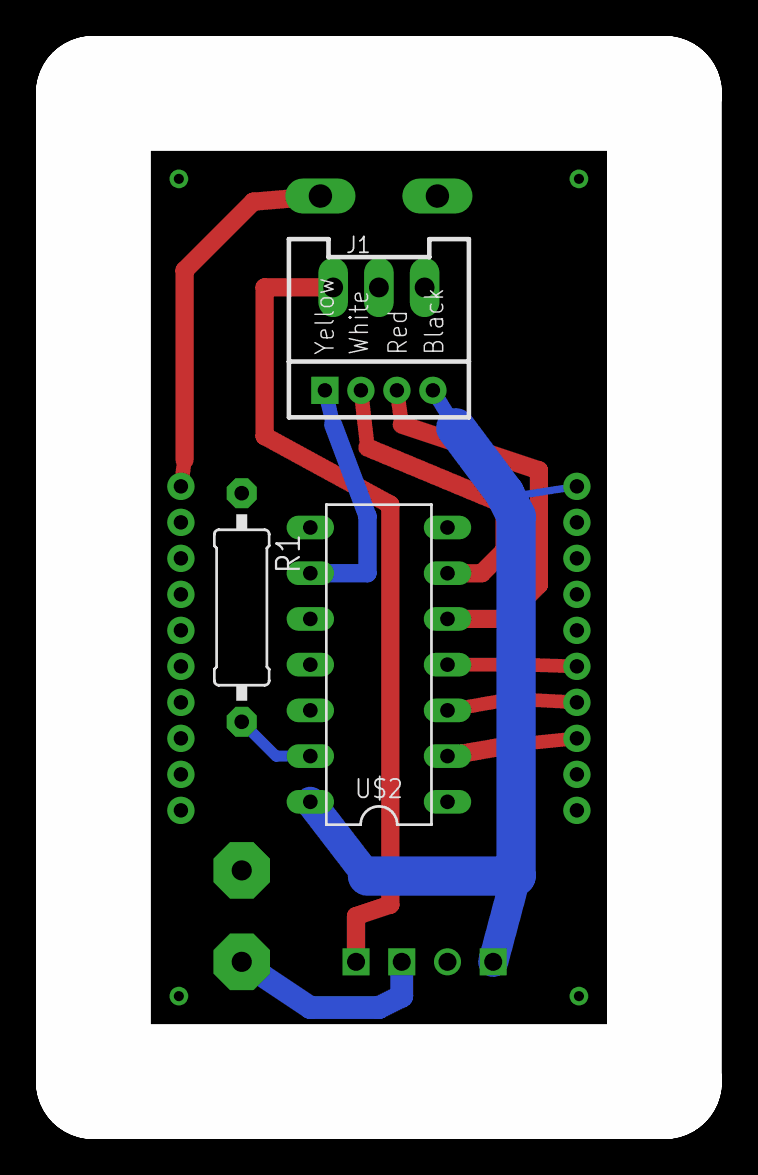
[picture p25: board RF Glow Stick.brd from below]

Board: 2 copper layers, 31.8 x 54.9 mm, 8 parts (3 on the bottom side), 12 nets.

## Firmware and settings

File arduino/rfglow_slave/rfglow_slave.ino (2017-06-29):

#include <ClickButton.h>

#include <EEPROM.h>
#include "panstamp.h"
#include "cc1101.h"
#include "calibration.h"

// My Debug Setup

//#define DEBUG
#ifdef DEBUG
  #define DEBUG_PRINTLN(x) Serial.println (x)
  #define DEBUG_PRINT(x) Serial.print (x)
#else
  #define DEBUG_PRINTLN(x)
  #define DEBUG_PRINT(x)
#endif


// ShiftPWM Setup
#define SHIFTPWM_NOSPI
const int ShiftPWM_latchPin = 9;
const int ShiftPWM_clockPin = 8;
const int ShiftPWM_dataPin = 7;

const bool ShiftPWM_invertOutputs = false;
const bool ShiftPWM_balanceLoad = false;
#include <ShiftPWM.h>

unsigned char maxBrightness = 16;
unsigned int pwmFrequency = 1200;
int numRegisters = 1;

// CC1101 Setup
byte networkAddress[] = {39,0};
byte receiverAddress = 5;
//byte syncWord[] = {39,39};

#define RFCHANNEL 2

CC1101 cc1101;

boolean packetAvailable = false;

// Power setup #defines
#define power_adc_enable()      (PRR &= (uint8_t)~(1 << PRADC))
#define power_adc_disable()     (PRR |= (uint8_t)(1 << PRADC))

#define power_spi_enable()      (PRR &= (uint8_t)~(1 << PRSPI))
#define power_spi_disable()     (PRR |= (uint8_t)(1 << PRSPI))

#define power_usart0_enable()   (PRR &= (uint8_t)~(1 << PRUSART0))
#define power_usart0_disable()  (PRR |= (uint8_t)(1 << PRUSART0))

#define power_timer0_enable()   (PRR &= (uint8_t)~(1 << PRTIM0))
#define power_timer0_disable()  (PRR |= (uint8_t)(1 << PRTIM0))

#define power_timer1_enable()   (PRR &= (uint8_t)~(1 << PRTIM1))
#define power_timer1_disable()  (PRR |= (uint8_t)(1 << PRTIM1))

#define power_timer2_enable()   (PRR &= (uint8_t)~(1 << PRTIM2))
#define power_timer2_disable()  (PRR |= (uint8_t)(1 << PRTIM2))

#define power_twi_enable()      (PRR &= (uint8_t)~(1 << PRTWI))
#define power_twi_disable()     (PRR |= (uint8_t)(1 << PRTWI))

ClickButton button(18, LOW, CLICKBTN_PULLUP);

void cc1101Interrupt(void) {
  packetAvailable = true;
}

void setup()
{
 
  power_adc_disable();
  
  #ifdef DEBUG
    Serial.begin(38400);
  #endif
  DEBUG_PRINTLN("Setup started");

  // Init CC1101
  cc1101.init();
  //cc1101.reset();
  
  configRadio4800v();
  //configRadio1200f();

  // These are all set by writeReg() directly now
  //cc1101.setChannel(RFCHANNEL, true);
  //cc1101.setSyncWord(syncWord, true);
  //cc1101.setCarrierFreq(CFREQ_868);  
  //cc1101.setDevAddress(receiverAddress, true);
  
  cc1101.disableAddressCheck();
  
  // Calibrate internal RC oscillator
  //rcOscCalibrate();
  
  delay(100);
  
  cc1101.setRxState();
  
  attachInterrupt(0, cc1101Interrupt, FALLING);

  ShiftPWM.SetAmountOfRegisters(numRegisters);
  ShiftPWM.SetPinGrouping(1);
  ShiftPWM.Start(pwmFrequency, maxBrightness);
  ShiftPWM.SetAll(0);
  ShiftPWM.OneByOneFast();
  
  #ifdef DEBUG
    //ShiftPWM.PrintInterruptLoad();
  #endif
  DEBUG_PRINTLN(ShiftPWM.m_ledFrequency);
  DEBUG_PRINTLN(ShiftPWM.m_maxBrightness);
  DEBUG_PRINTLN("Setup complete");
  
  button.debounceTime = 20;
  button.multiclickTime = 85;
  button.longClickTime = 1000;
}

#define RF_LOCKOUT_MS 2500
unsigned long lastCmdMs = 0;

unsigned int mH = 0;
unsigned int mS = 255;
unsigned int mB = 60;

int clickState = 0;

#define AUTO_INTERVAL 100
boolean isAutoCycle = false;
unsigned long prevMs = 0;

void loop() {
  
  unsigned long curMs = millis();
  
  if(packetAvailable) {
    packetAvailable = false;
    CCPACKET packet;
    
    detachInterrupt(0);
    
    if(cc1101.receiveData(&packet) > 0) {
      if (packet.crc_ok && packet.length > 1) {
        processData(packet.data);
      }
    }
    attachInterrupt(0, cc1101Interrupt, FALLING);
  }
  
  button.Update();
  
  if (curMs - lastCmdMs > RF_LOCKOUT_MS) {
    if (button.clicks != 0) {
      clickState = button.clicks;
    }
    
    if (button.clicks == 1) {
      isAutoCycle = false;
      mH = (mH + 60) % 360;
      ShiftPWM.SetHSV(0, mH, mS, mB);
    }
    
    if (button.clicks == 2) {
      isAutoCycle = !isAutoCycle;
    }
    
    if (button.clicks < 0) {
      mB = (mB + 60) % 240;
      ShiftPWM.SetHSV(0, mH, mS, mB);
    }
    
    if (isAutoCycle) {
      if (curMs - prevMs > AUTO_INTERVAL) {
        mH = (mH + 60) % 360;
        ShiftPWM.SetHSV(0, mH, mS, mB);
        prevMs = curMs;
      }
    } else {
      prevMs = curMs;
    } 
  }
}

void processData(byte *data) {

  unsigned int hue;
  unsigned int saturation;
  unsigned int brightness;

  hue = ((data[1] << 8) + data[2]);
  saturation = data[3];
  brightness = data[4];
  
/*
  hue = ((data[1] << 8) + data[2]);
  saturation = ((data[3] << 8) + data[4]);
  brightness = ((data[5] << 8) + data[6]);
*/

  DEBUG_PRINT("Received values: ");
  DEBUG_PRINT(hue);
  DEBUG_PRINT(", ");
  DEBUG_PRINT(saturation);
  DEBUG_PRINT(", ");
  DEBUG_PRINTLN(brightness);

  ShiftPWM.SetHSV(0, hue, saturation, brightness);
  
  lastCmdMs = millis();
}

void configRadio4800v() {
  // settings for 4.8kbps variable packet size
  
  cc1101.writeReg(CC1101_IOCFG2,0x29);  //GDO2 Output Pin Configuration
  cc1101.writeReg(CC1101_IOCFG1,0x2E);  //GDO1 Output Pin Configuration
  cc1101.writeReg(CC1101_IOCFG0,0x06);  //GDO0 Output Pin Configuration
  cc1101.writeReg(CC1101_FIFOTHR,0x47); //RX FIFO and TX FIFO Thresholds
  cc1101.writeReg(CC1101_SYNC1,0xD3);   //Sync Word, High Byte
  cc1101.writeReg(CC1101_SYNC0,0x91);   //Sync Word, Low Byte
  cc1101.writeReg(CC1101_PKTLEN,0xFF);  //Packet Length
  cc1101.writeReg(CC1101_PKTCTRL1,0x07);//Packet Automation Control
  cc1101.writeReg(CC1101_PKTCTRL0,0x45);//Packet Automation Control
  cc1101.writeReg(CC1101_CHANNR,0x00);  //Channel Number
  cc1101.writeReg(CC1101_FSCTRL1,0x06); //Frequency Synthesizer Control
  cc1101.writeReg(CC1101_FSCTRL0,0x00); //Frequency Synthesizer Control
  cc1101.writeReg(CC1101_FREQ2,0x23);   //Frequency Control Word, High Byte
  cc1101.writeReg(CC1101_FREQ1,0x31);   //Frequency Control Word, Middle Byte
  cc1101.writeReg(CC1101_FREQ0,0x3B);   //Frequency Control Word, Low Byte
  cc1101.writeReg(CC1101_MDMCFG4,0xC7); //Modem Configuration
  cc1101.writeReg(CC1101_MDMCFG3,0x83); //Modem Configuration
  cc1101.writeReg(CC1101_MDMCFG2,0x03); //Modem Configuration
  cc1101.writeReg(CC1101_MDMCFG1,0x22); //Modem Configuration
  cc1101.writeReg(CC1101_MDMCFG0,0xF8); //Modem Configuration
  cc1101.writeReg(CC1101_DEVIATN,0x40); //Modem Deviation Setting
  cc1101.writeReg(CC1101_MCSM2,0x07);   //Main Radio Control State Machine Configuration
  cc1101.writeReg(CC1101_MCSM1,0x30);   //Main Radio Control State Machine Configuration
  cc1101.writeReg(CC1101_MCSM0,0x18);   //Main Radio Control State Machine Configuration
  cc1101.writeReg(CC1101_FOCCFG,0x16);  //Frequency Offset Compensation Configuration
  cc1101.writeReg(CC1101_BSCFG,0x6C);   //Bit Synchronization Configuration
  cc1101.writeReg(CC1101_AGCCTRL2,0x43);//AGC Control
  cc1101.writeReg(CC1101_AGCCTRL1,0x40);//AGC Control
  cc1101.writeReg(CC1101_AGCCTRL0,0x91);//AGC Control
  cc1101.writeReg(CC1101_WOREVT1,0x87); //High Byte Event0 Timeout
  cc1101.writeReg(CC1101_WOREVT0,0x6B); //Low Byte Event0 Timeout
  cc1101.writeReg(CC1101_WORCTRL,0xF8); //Wake On Radio Control
  cc1101.writeReg(CC1101_FREND1,0x56);  //Front End RX Configuration
  cc1101.writeReg(CC1101_FREND0,0x10);  //Front End TX Configuration
  cc1101.writeReg(CC1101_FSCAL3,0xE9);  //Frequency Synthesizer Calibration
  cc1101.writeReg(CC1101_FSCAL2,0x2A);  //Frequency Synthesizer Calibration
  cc1101.writeReg(CC1101_FSCAL1,0x00);  //Frequency Synthesizer Calibration
  cc1101.writeReg(CC1101_FSCAL0,0x1F);  //Frequency Synthesizer Calibration
  cc1101.writeReg(CC1101_RCCTRL1,0x41); //RC Oscillator Configuration
  cc1101.writeReg(CC1101_RCCTRL0,0x00); //RC Oscillator Configuration
  cc1101.writeReg(CC1101_FSTEST,0x59);  //Frequency Synthesizer Calibration Control
  cc1101.writeReg(CC1101_PTEST,0x7F);   //Production Test
  cc1101.writeReg(CC1101_AGCTEST,0x3F); //AGC Test
  cc1101.writeReg(CC1101_TEST2,0x81);   //Various Test Settings
  cc1101.writeReg(CC1101_TEST1,0x35);   //Various Test Settings
  cc1101.writeReg(CC1101_TEST0,0x09);   //Various Test Settings
}

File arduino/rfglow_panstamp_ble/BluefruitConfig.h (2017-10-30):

// COMMON SETTINGS
// ----------------------------------------------------------------------------------------------
// These settings are used in both SW UART, HW UART and SPI mode
// ----------------------------------------------------------------------------------------------
#define BUFSIZE                        128   // Size of the read buffer for incoming data
#define VERBOSE_MODE                   true  // If set to 'true' enables debug output
#define BLE_READPACKET_TIMEOUT         500   // Timeout in ms waiting to read a response


// SHARED SPI SETTINGS
// ----------------------------------------------------------------------------------------------
// The following macros declare the pins to use for HW and SW SPI communication.
// SCK, MISO and MOSI should be connected to the HW SPI pins on the Uno when
// using HW SPI.  This should be used with nRF51822 based Bluefruit LE modules
// that use SPI (Bluefruit LE SPI Friend).
// ----------------------------------------------------------------------------------------------
#define BLUEFRUIT_SPI_CS               10
#define BLUEFRUIT_SPI_IRQ              9
#define BLUEFRUIT_SPI_RST              8    // Optional but recommended, set to -1 if unused

// SOFTWARE SPI SETTINGS
// ----------------------------------------------------------------------------------------------
// The following macros declare the pins to use for SW SPI communication.
// This should be used with nRF51822 based Bluefruit LE modules that use SPI
// (Bluefruit LE SPI Friend).
// ----------------------------------------------------------------------------------------------
#define BLUEFRUIT_SPI_SCK              14
#define BLUEFRUIT_SPI_MISO             22
#define BLUEFRUIT_SPI_MOSI             11

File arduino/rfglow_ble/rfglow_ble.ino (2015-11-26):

#include <SPI.h>
#include "Adafruit_BLE_UART.h"

#include "spip.h"
#include "EEPROM.h"
#include "cc1101.h"
#include "WString.h"
#include "calibration.h"


// My Debug Setup
#define DEBUG
#ifdef DEBUG
  #define DEBUG_PRINTLN(x) Serial.println (x)
  #define DEBUG_PRINT(x) Serial.print (x)
  #define DEBUG_PRINT2(x,y) Serial.print (x,y)
#else
  #define DEBUG_PRINTLN(x)
  #define DEBUG_PRINT(x)
  #define DEBUG_PRINT2(x,y)
#endif

// CC1101 Setup
byte networkAddress[] = {39,0};
byte senderAddress = 4;
byte receiverAddress = 5;
//byte syncWord[] = {39,39};

#define RFCHANNEL 2

#define PA_EN_PIN 8
#define CC1101_CS_PIN 10

CC1101 cc1101;

// nRF8001 BLE setup
#define ADAFRUITBLE_RST 9
#define ADAFRUITBLE_REQ 4
#define ADAFRUITBLE_RDY 3
// Pin 3 is on interrupt 1 (Pin 2, the library default is on interrupt 0 but in use)
Adafruit_BLE_UART BTLEserial = Adafruit_BLE_UART(ADAFRUITBLE_REQ, ADAFRUITBLE_RDY, ADAFRUITBLE_RST);

int isBLEInit = 0;

// Update settings
#define MIN_LED_UPDATE_INTERVAL_MS 120
#define SENDS_ON_CHANGE 4
#define PERIODIC_RESEND_MS 1000

void setup()
{
  pinMode(PA_EN_PIN, OUTPUT);
  digitalWrite(PA_EN_PIN, LOW);

  //enterPanStampSPI();

  // Calibrate internal RC oscillator
  rcOscCalibrate();
  
  #ifdef DEBUG
    Serial.begin(38400);
  #endif
  DEBUG_PRINTLN("start");

  // initialize the RF Chip
  cc1101.setTxPowerAmp(0x80);
  cc1101.init();
  
  configRadio4800v();

  DEBUG_PRINTLN("radio initialized");

  DEBUG_PRINT("Sender address = ");
  DEBUG_PRINTLN(senderAddress);
  DEBUG_PRINT("Receiver address = ");
  DEBUG_PRINTLN(receiverAddress);
  
  //leavePanStampSPI();

  //BTLEserial.setRXcallback(rxCallback);
  //BTLEserial.setACIcallback(aciCallback);
  //BTLEserial.setDeviceName("RFGLOW");
  //BTLEserial.begin();
}

unsigned long previousMs = 0;
unsigned int sends = 255;
unsigned int c_hue = 0, c_saturation = 0, c_brightness = 0;

aci_evt_opcode_t laststatus = ACI_EVT_DISCONNECTED;

void loop() {
  unsigned long currentMs = millis();
  
  // Tell the nRF8001 to do whatever it should be working on.
  //BTLEserial.pollACI();
  
  // Only check for a pending update if more than LED_UPDATE_INTERVAL_MS
  // has passed since we last sent an update
  if (currentMs - previousMs > MIN_LED_UPDATE_INTERVAL_MS) {
    if (sends < SENDS_ON_CHANGE) {
      // We have a change where we have not yet sent all our requested updates
      sendCurrentColor();
      sends++;
      previousMs = currentMs;
    } else if (currentMs - previousMs > PERIODIC_RESEND_MS) {
      // It's been more than the periodic resend interval
      sendCurrentColor();
      previousMs = currentMs;
    } else {
      // We have no pending changes and it's not yet time for a periodic
      // resend, so do nothing
    }
  }
}

void rxCallback(uint8_t *buffer, uint8_t len)
{
  DEBUG_PRINT(F("Received "));
  DEBUG_PRINT(len);
  
  DEBUG_PRINT(F(" bytes: "));
  
  for(int i=0; i<len; i++)
   DEBUG_PRINT((char)buffer[i]); 

  DEBUG_PRINT(F(" ["));

  for(int i=0; i<len; i++) {
    DEBUG_PRINT(" 0x");
    DEBUG_PRINT2((char)buffer[i], HEX); 
  }
  DEBUG_PRINT(F(" ]"));
  
  DEBUG_PRINTLN("");

  if (len == 4) {
    // 4 bytes means treat as 1 16-bit and 2 8-bit uints directly
    c_hue = (buffer[0] << 8) + buffer[1];
    c_saturation = buffer[2];
    c_brightness = buffer[3];
    sends = 0;
    DEBUG_PRINT("Directly read: ");
    DEBUG_PRINT(c_hue);
    DEBUG_PRINT(", ");
    DEBUG_PRINT(c_saturation);
    DEBUG_PRINT(", ");
    DEBUG_PRINTLN(c_brightness);
  } else if (len <= 11) {
    // safe number of bytes in the packet
    char inData[len+1];

    memcpy(inData, buffer, len);
    inData[len] = 0;
    
    unsigned int hue, saturation, brightness;
    int numExtracted = sscanf(inData,"%u %u %u",&hue,&saturation,&brightness);
    DEBUG_PRINT("Parsed fields: ");
    DEBUG_PRINTLN(numExtracted);
    if (numExtracted == 3) {
      c_hue = hue;
      c_saturation = saturation;
      c_brightness = brightness;
      sends = 0;
      DEBUG_PRINT("Parsed values: ");
      DEBUG_PRINT(c_hue);
      DEBUG_PRINT(", ");
      DEBUG_PRINT(c_saturation);
      DEBUG_PRINT(", ");
      DEBUG_PRINTLN(c_brightness);
    }
  } else {
    // Buffer has some illegal amount of data
    while (BTLEserial.available()) {
      BTLEserial.read();
    }
    DEBUG_PRINTLN("Trashed unparseable packet");
  }
}


void sendCurrentColor() {
  sendCommand(c_hue, c_saturation, c_brightness);
}

void sendCommand(uint16_t hue, uint8_t saturation, uint8_t brightness) {
  CCPACKET packet;

  packet.length = 5;
  packet.data[0] = receiverAddress;
  packet.data[1] = (hue >> 8) & 0xFF;
  packet.data[2] = hue & 0xFF;
  packet.data[3] = saturation;
  packet.data[4] = brightness;

  /*
  packet.data[1] = (hue >> 8) & 0xFF;
  packet.data[2] = hue & 0xFF;
  packet.data[3] = (saturation >> 8) & 0xFF;
  packet.data[4] = saturation & 0xFF;
  packet.data[5] = (brightness >> 8) & 0xFF;
  packet.data[6] = brightness & 0xFF;
  */

  /*
  Serial.println(packet.length);
  for (int i = 0; i < packet.length; i++) {
    Serial.println(packet.data[i]);
  }
  */
 
  digitalWrite(PA_EN_PIN, HIGH);
  //delay(10);
  if(sendData(packet)){
    DEBUG_PRINT(">");
  } else {
    DEBUG_PRINT("X");
  }
  digitalWrite(PA_EN_PIN, LOW);
}

boolean sendData(CCPACKET packet) {
  noInterrupts();
  enterPanStampSPI();
  boolean result = cc1101.sendData(packet);
  leavePanStampSPI();
  interrupts();
  return result;
}

void enterPanStampSPI(void){
  // prepare SPI mode for panStamp
  digitalWrite(SPI_SCK, LOW);
  digitalWrite(SPI_MOSI, LOW);
  digitalWrite(ADAFRUITBLE_REQ, HIGH);
  digitalWrite(CC1101_CS_PIN, LOW);

  //SPCR = 0;
  //SPSR = 0;
  SPCR = _BV(SPE) | _BV(MSTR);
}

void leavePanStampSPI(void){
  // prepare SPI mode for ethernet
  digitalWrite(SPI_MOSI, LOW);
  digitalWrite(SPI_SCK, LOW);
  digitalWrite(CC1101_CS_PIN, HIGH);
  digitalWrite(ADAFRUITBLE_REQ, LOW);
  
  SPCR = 0;
  SPSR = 0;
  SPSR = (1<<SPI2X);
  SPCR = ((1<<SPE)|(1<<MSTR)|(0<<SPR1) | (1<<SPR0) | (1<<DORD) | (0<<CPOL) | (0<<CPHA));
}

void aciCallback(aci_evt_opcode_t event)
{
  switch(event)
  {
    case ACI_EVT_DEVICE_STARTED:
      DEBUG_PRINTLN(F("Advertising started"));
      isBLEInit = 1;
      break;
    case ACI_EVT_CONNECTED:
      DEBUG_PRINTLN(F("Connected!"));
      break;
    case ACI_EVT_DISCONNECTED:
      DEBUG_PRINTLN(F("Disconnected or advertising timed out"));
      break;
    default:
      break;
  }
}
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

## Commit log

2014-09-08 Updated slave to PWM at 1200Hz Master now has on/off controls via long-press
2014-09-08 Reorganized output gerbers Updated schemate to move power switch to front end and a tactile switch to PC4 (Arduino pin 18)
    [RF Glow Stick.brd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]
2014-09-08 Reorganized eagle files Added fillets to handles and include printable STL files
    [DiffuserCoupler.ipt, DiffuserCoupler.stl, Handle-Bottom.ipt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]
2014-09-13 Disable adc to save an undetectable amount of power. Real power draw is from the CC1101
2014-09-13 Updated design to prevent holes in the shell due to fillets, shore up the wobbly coupler, and split the top into a battery and main portion
    [DiffuserCoupler.ipt, DiffuserCoupler.stl, Handle-Bottom.ipt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]
2014-10-05 Fixed flawed board design. The LED connector needs to be in the middle to clear the PCB holding ledges and to have maximum clearance for round handles. Also reduced the side of the board from 5.08cm 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
    [RF Glow Stick.GBL, RF Glow Stick.GBO, RF Glow Stick.GBP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]
2014-10-05 Added cutouts to the handle top to access the switches in the v2 pcb design. Thickened many handle walls to 1.5mm
    [DiffuserCoupler.ipt, DiffuserCoupler.stl, Handle-Bottom.ipt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]
2014-10-26 Added magnet pockets and verified cutout for switches is functional.
    Cutout in coupler for alignment tabs is not quite right, still reqires filing for the bottom
    [DiffuserCoupler.stl, Handle-Bottom.ipt, Handle-Bottom.stl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]
2014-10-26 Updated board to be compatible with milling fabrication (e.g. a CNC mill with an engraving tool for isolation routing). However, actual isolution routed board is nonfunctional because the design reli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
    [RF Glow Stick.GBL, RF Glow Stick.GBO, RF Glow Stick.GBP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]
2014-10-26 Added serial output when commands are received for easier debugging of newly flashed boards.
2014-10-31 Changed protocol to reduce fixed packet length from 0x10 to 0x5 bytes. Added a BLE master which relays messages from a BLE Central device to the glow sticks to enable app-based control. (Using Adafru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
    [rfglow_ble.ino, rfglow_master.ino, rfglow_slave.ino]
2014-10-31 Added dependant Arduino libraries as submodules (for those which are in github) or copies (for those which are not)
2014-10-31 Added additional clearance to lip and widened battery lead clearance holes
    [DiffuserCoupler.ipt, DiffuserCoupler.stl, Handle-Bottom.ipt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]
2014-10-31 Added isolation milling gcode for shopbot Mainly as an example, since isolation milled boards are nonfunctional unless the through holes are plated somehow
2014-10-31 Added .gitmodules for github based arduino library submodules
2014-11-04 Added BLE master eagle files
    [BLE Master.brd, BLE Master.sch]
2014-11-04 Added Arduino code for the BLE master
2015-11-03 Add mobile app code
    [DiffuserCoupler.ipt, DiffuserCoupler.stl, Handle-Bottom.ipt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]
2015-11-26 Updated slave to make use of the button
2017-06-29 Catchup update, sorry...
    [DiffuserCoupler.ipt, Handle-Bottom.ipt, Handle-Bottom.stl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]
2017-07-14 Update for multi-card swipe buttons and telemetry
2017-07-16 Adding new code for using the TI TCL59116 LED driver
2017-07-25 Added new slave board for tlc59116
    [PCB-Main-BOM.csv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]
2017-08-17 CLeaned up gerbers, fixed serious circuit errors
    [PCB-Main-BOM.csv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]
2017-08-20 Updates to board
    [PCB-Main.brd, PCB-Main.sch]
2017-08-21 Update code to OneButton, and switch to use library-controlled arduino-TCL59116.
2017-08-26 Updated Arduino code for Panstamp SDK 1.5.7 and Arduino IDE 1.8.3, using boards. Radio configuration is now done in the board library in cc1101.h instead of in this code.
2017-10-30 Added code for the BLE controller implemented with a PanStamp long distance board and the Adafruit Bluefruit LE SPI Friend
2017-11-13 Added some models for tlc59116 accessories
    [Box - Part 1.stl, Box - Part 2.stl, Cap-Solid.stl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]
2017-11-20 Added untested code for controlling current
2017-12-05 Fixes based on field test
    [rfglow_panstamp_ble.ino, rfglow_tcl591xx.ino]
2017-12-27 Component setup for Panstamp LD to BLE relay board
2018-04-13 Adding components to build PCB for relay
2018-05-05 Real PCB for relay board, update handle to reduce submodules and use a u.FL antenna connector.
    [PCB-Main.brd, PCB-Main.sch, PCB-Main_Seeed_BOM.csv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]
2018-05-07 Adding Wear OS controller
    [Box - Part 1.stl, Box - Part 2.stl]
2018-05-21 Cloud Firestore based button config complete
2018-06-25 Menu system functional, FHSS functional. Working on relay box fades
2018-06-27 Relay controlled fading works. Pass 6 bytes instead of 4 over BLE, and the last 2 bytes will be interpreted as an unsigned int for the ms to transition from current color to the payload defined color.
2018-06-27 A few fixes to handle maLevel properly
    [rfglow_panstamp_ble.ino]
2018-07-03 Fix button lockout interaction with FHSS
    [rfglow_tcl591xx.ino]
2018-11-27 Updated button pin for newest board design
2018-12-27 Updated BLE connection for Wear OS client to connect to device MAC rather than scanning.
    Attempt to better locate the relay when the number of BLE devices present is high.
2019-02-24 Clean up schematic
    [PCB-Main.brd, PCB-Main.sch]
2019-02-26 Begin esp32 board version
    [PCB-Main.brd, PCB-Main.sch]
2019-03-02 Consolidate libraries, swap regulator
    [PCB-Main.brd, PCB-Main.sch]
2019-03-04 Removed unused parts for esp32, begin integrating actual module
    [PCB-Main.brd, PCB-Main.sch]
2019-03-08 Board layout with UART but without LIPO charger, submitted this one to PCBA
    [PCB-Main.brd, PCB-Main.sch]
2019-04-15 Add esp32 arduino project
    [PCB-Main.brd]
2019-05-22 Software work for ESP32 version
    [Handle-Set.stl, LED Tab Profile.dxf]
2019-05-22 Add BOM for esp32 PCB
    [PCB-Main-BOM.xlsx]
2019-05-24 ESP32 single stick control via BLE
2019-05-30 Mesh basically working with BLE and button
2019-06-08 BLE-Mesh relaying is reasonably reliable now.
2019-06-23 Mesh stability tests, but these don't work
    [main.cpp, rfglow_globals.h]
2019-06-23 ESP-NOW broadcast now working, both BLE & switches No repeating/rebroadcasting yet.
2019-06-24 Use unions for protocol, drop CPU clock for power.
2019-06-27 Change button behavior to be more like the X10-III instead of RGBCMY.
2019-07-02 Minor power tuning
2019-10-24 Changed double-click, updated android project. vBatLED() can sometimes crash, plus is not accurate if measured while the light is on.
    [main.cpp]

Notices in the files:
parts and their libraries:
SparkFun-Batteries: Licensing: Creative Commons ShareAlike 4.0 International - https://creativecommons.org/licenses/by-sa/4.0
